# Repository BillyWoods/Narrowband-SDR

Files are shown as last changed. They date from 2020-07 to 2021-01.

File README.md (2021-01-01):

# Narrowband-SDR
A four-channel narrowband SDR receiver based around the Mirics MSi001, Maxim MAX19777 and Cypress FX2LP.

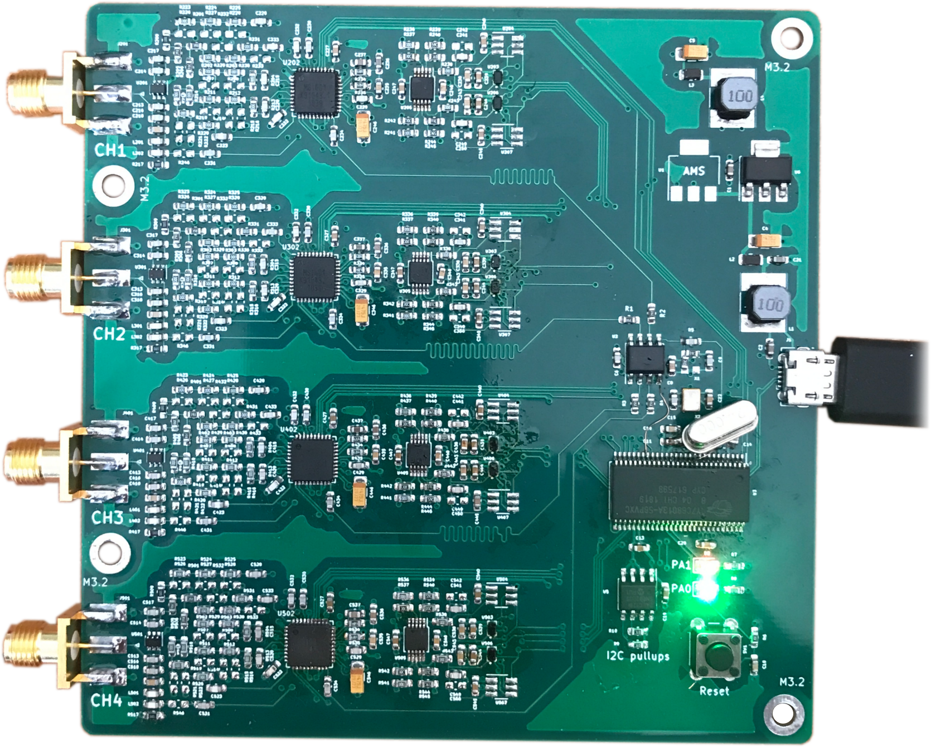
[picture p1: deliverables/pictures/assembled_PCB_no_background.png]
PCB picture
|  | system diagram |
|---|---|
| single channel spectrogram | four channel time domain |

## Project Layout
* Simulations of the RF architecture are in the **simulations/** folder.
* KiCAD PCB designs are in the **pcb/** folder.
* Firmware running on the Cypress FX2LP is stored in the **fx2fw/fx2sdr** folder. A copy of fx2lib is also included, which the firmware is built on, and fx2lib also provides utilities to upload/program the firmware to the device (fx2load).
* A branch of GNURadio (WiP) with support for this SDR is under development in the **host/** folder. However, at present data is pulled off the SDR and stored into raw files for later analysis using a tool in **fx2fw/uhd_driver**.

## Dependencies
fx2lib has a few dependencies, which are needed to compile the firmware:
* make
* gcc
* libusb-1.0
* SDCC
* python 2.7
* swig

Having libusb installed will also allow the host utility to be compiled.

## Acknowledgements
I would  like  to  thank Dr  Emanuele  Viterbo, of Monash University’s ECSE faculty, who supervised the project at its inception and assisted in developing its scope.

The open source Sigrok project must be acknowledged for serving as an example of how to use the FX2LP at the core of this SDR for high speed data acquisition.  Similarly, the Osmocom project, which provides a driver for the tuners used in this SDR, has assisted with interfacing and configuring the MSi001 tuners used in this project.

[Antti's LinuxTV Blog](http://blog.palosaari.fi/2013/10/naked-hardware-13-logitec-ldt-1s310uj.html) provided pictures of the PCB of an actual MSi001 implementation which were vital to developing the schematics for this project.

## Further Documentation
For more details on the project, see the [final report](deliverables/FYP_report_final.pdf).

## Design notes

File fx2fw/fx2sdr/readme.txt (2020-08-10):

gpif_waveforms.gpf is a file for/created in the Cypress GPIF designer.
gpif_waveforms.c is exported from the Cypress GPIF Designer.
gpif_dat.c is autogenerated from gpif_waveforms.c by the Makefile

Starting a new firmware is easy.

1) The fw should build without modification.

> make # builds firmware.ihx
> make bix # builds firmware.bix
> make iic # builds firmware.iic

2) modify device.c to initialize your device and
   handle data according to your needs.

3) add more sources, gpif data etc.

4) modify the device descriptor (dscr.a51)

For a fast way to deploy, you can use the fx2load
package provided in examples/fx2

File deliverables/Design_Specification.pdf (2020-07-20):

# ECE 4094 Project A

# (SDR for Sounding Rocket Telemetry)

# Design Specification

| First Name | Last name | ID | Email
Supervisor | Emanuele | Viterbo | | Emanuele.Viterbo@monash.edu
Student 1 | William | Woods | 28806506 | wwoo0003@student.monash.edu

### Table of Contents

Introduction | 1
System Specifications | 1
Parts List | 1
Design Choices | 2
Narrowband vs. Wideband | 2
Multi-channel functionality | 2
Moving to a Receive-Only SDR (Originally Intended to Have Receive and Transmit) | 3
Extending to Four Receive Channels (Originally Two) | 3
Inclusion of a Low-Noise Amplifier (LNA) as a Pre-Amplifier | 3
Radiofrequency (RF) Front-End | 4
Software System | 5
References | 5

### Tables and Figures

Table 1: Parts List | 1
Figure 1: Electronics System Diagram | 4
Figure 2: Software System Diagram | 5

## Introduction

This design specification details the software and hardware architecture for a four-channel narrowband software-defined radio (SDR) receiver. It is the culmination of my FYP research in semester one so far, and it explains the rationale for changes that have been made to the initial proposal and updates the initial specifications to reflect what is realisable with the hardware that has been selected.
This specification also serves to allow verification of the soundness of the architecture, allow detailed design of a PCB and allow the development of software needed to tie this SDR into the existing ecosystem of open source SDR software. For a detailed breakdown of future tasks which need to be completed, and the timeline for doing so, including a Gantt chart, see the Progress Report.
For context, this project is primarily intended to be for use with Monash High Powered Rocketry’s rockets, originally as both the rocket-mounted telemetry transmitter and as the ground station receiver. However, as this specification will explain, with the design moving to be a receiver only, it will find use only in the latter application. Other secondary applications for this project are also expected to be found, given its multi-channel capability.

## System Specifications

At this stage of design, with the components selected, the system will meet the following specifications:
- Four independently tuneable receive channels
- 50Ω impedance inputs
- 3M 12-bit samples/second, which can be divided amongst the four channels, each channel having two outputs for I and Q
- Configurable receiver bandwidths of 200kHz and 300kHz
- 150kHz to 1.8GHz tuneable range

### Parts List

Table 1: Parts List
Part | Description | Cost, approx., AUD | Qty | Total Cost | Supplier
NXP BGU7045 | Low-noise amplifier (LNA) with bypass. Operates up to 1000 MHz and is used because it has a lower noise figure than the MSi001’s internal LNAs over that range. | $1 | 4 | $4 | Element 14, Mouser, Digi-Key, LCSC
Mirics MSi001 | Integrated multiband tuner chip. It is controlled over SPI and has baseband analogue I/Q outputs (two differential pairs, i.e. four lines). | $3 | 4 | $12 | AliExpress

Maxim MAX11131 | 12-bit ADC. 3Msps multiplexed between all input channels. The multiplexing scheme can be configured to automatically follow a schedule of which channels to sample from. | $15 | 1 | $21 | Element 14, Mouser, Digi-Key
Cypress FX2LP | USB 2.0 bridge. Used for reading samples from the ADC and transferring them over USB. Also takes commands from the PC and controls the tuners. | $20 | 1 | $21 | Element 14, Mouser, Digi-Key, LCSC, AliExpress
22 MHz TXCO, 2 ppm | Precision frequency reference. This will supply the tuners, with the ADC and the USB bridge chip supplied by another source. | $5 | 1 | $5 | Element 14, Mouser, Digi-Key, LCSC
Printed Circuit Board (PCB) | 4-layer PCB, smaller than 100 x 100mm. Price includes registered shipping and minimum order quantity of five pieces. | $40 | 1 | $40 | JLCPCB
Total | | | | $103

### Design Choices

Narrowband vs. Wideband
There are existing SDR radios which work on bandwidths in the range of tens of megahertz, however these are expensive systems, particularly due to cost in the area of digitisation (the ADC) and digital electronics required as data rates increase.
Each of the radiofrequency (RF) tuners proposed for this design can provide reception of almost 10MHz of bandwidth and provide convenient analogue baseband I/Q outputs, so it is unfortunate to be underutilising these tuners in this project. However, to fully utilise the MSi001 tuners would push this SDR up into the price range and capability of pre-existing SDR systems; see the SDRplay RSP1A [1] for an existing single-channel receiver which fully utilises the MSi001.
To avoid re-inventing the wheel, it has been decided to differentiate this project by providing narrowband reception only, and thus saving on cost. There are still many things possible with a narrowband SDR (especially an SDR with four channels), and reception of most of the telemetry systems Monash High Powered Rocketry uses would be covered.
Multi-channel functionality
When the project was conceived, it was specified that the SDR should have multiple receivers synchronised to the same frequency reference. This choice was made because there are few affordable multi-channel SDRs available, yet such an SDR would be useful for experiments with diversity, direction finding and potentially beam forming.

Moving to a Receive-Only SDR (Originally Intended to Have Receive and Transmit)
The design moved to be a receive-only radio system, making this radio suitable for the telemetry ground station, but not useful onboard a rocket, which has to transmit the data. This decision was made due to anticipating difficulties with licensing.
A non-assigned scientific licence [2] can be obtained from the Australian Communications and Media Authority (ACMA) which permits research, teaching, demonstrations and trials on a set of shared frequencies. In fact, low power experimentation with SDRs in a shielded lab environment is already done at Monash University, however the end goal is to use this SDR “in the wild” on an ongoing basis and not as a demonstration or trial. The most appropriate licence for this is the low interference potential devices (LIPD) class licence [3], which does not require operators to apply for a licence, and covers mobile phones, cordless handsets, Wi-Fi, alarm systems, as examples. An apparatus licence [4], of which the amateur apparatus licence (colloquially known as the “HAM licence”) is a type, can also allow operation on a few more bands and power levels, but requires an operator to apply for it. However, in order for any radio transmitter device to be supplied and used in Australia under the LIPD class licence, the device needs to be certified for compliance [5]. Getting an SDR transmitter certified was found to be unlikely because it is such a general device, able to operate over a wide range of spectrum, with infinitely many different modulation schemes and different power levels, while the LIPD class licence is very explicit about what combinations of modulation schemes, bands and power levels may be used [6]. A few existing SDRs with transmit capability (at least ones made/distributed by US companies), attempt, in some cases, to circumvent similar legislation in their jurisdiction by classing SDRs as test equipment, however this is evidently a grey area if one does not hold a scientific or apparatus licence to operate such test equipment.
In any case, the complexity of dealing with licensing was felt to detract from the objectives of learning about radio design and producing a readily useable SDR.
Extending to Four Receive Channels (Originally Two)
While searching for discrete components for the RF front end (such as mixers, frequency synthesisers and filters), it was discovered that because only receive capability is required, a range of highly integrated tuners/front ends normally intended for cable and terrestrial TV applications would be suitable. Since these tuners are cheap and require few additional components, the cost to add additional receive channels is surprisingly small, so it was felt that the extra cost and design size were easily justified by the potential of having four phase-coherent, separately tuneable channels. Inclusion of a Low-Noise Amplifier (LNA) as a Pre-Amplifier
The MSi001 tuner has integrated LNAs, however it was decided to include a discrete LNA to assist in three ways. Firstly, the noise figures of the integrated LNAs are approximately 6dB, whereas the external LNA which has been chosen (BGU7045), has a noise figure which is half this, and the noise introduced by amplifiers early in the chain is particularly crucial to performance. Secondly, the external LNAs have an IIP3 of 15dBm at max gain, which is greater than the IIP3 of approximately -10dBm which the MSi001 has at its max gain, indicating that the MSi001 will be more susceptible to intermodulation from powerful interferers if it is being run at max gain, so by not needing to run the MSi001 at max gain, its IIP3 is much improved. Thirdly, the MSi001 has a gap in its reception between approximately 240 – 470MHz, but luckily there is a ‘hack,’ or workaround, to allow operation in this band. The workaround involves routing the RF signal through a signal path within the tuner normally intended for reception between 150kHz to 30MHz. The integrated LNA and mixer used in this path are not expected to have much response to a signal that is so far outside their operating ranges, so the inclusion of an external LNA is intended to assist here.

## Radiofrequency (RF) Front-End

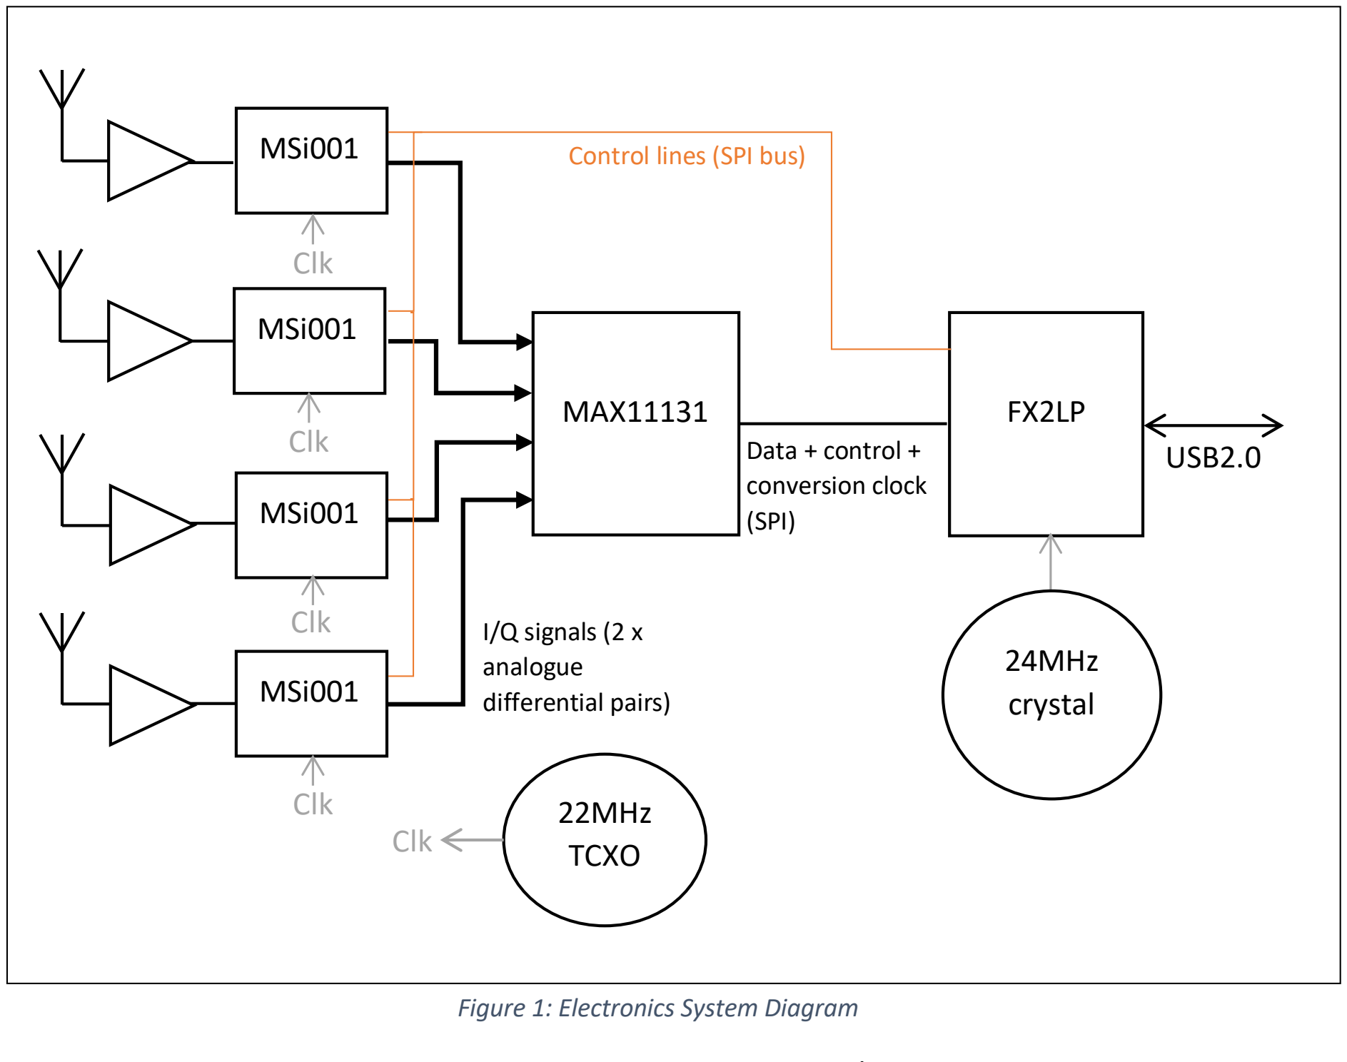
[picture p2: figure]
Figure 1: Electronics System Diagram; MSi001; MAX11131; 22MHz TCXO; Control lines (SPI bus); Clk; Data + control + conversion clock (SPI); USB2.0; I/Q signals (2 x analogue differential pairs); 24MHz crystal

All MSi001 tuners will run from the same precision oscillator/reference, while the FX2LP, per its datasheet, needs a 24MHz crystal. It is unfortunate that the MSi001 cannot operate from a 24MHz reference, otherwise an extra part could be eliminated. The FX2LP will be able to output a 48MHz clock on the SPI bus, which the ADC can use for both making conversions and communication.
Not pictured in Figure 1 is that the LNAs have internal bypass capability if no amplification is desired. This is controlled by setting the voltage of the gain control pin on the external LNAs to zero, so these control pins will be connected to the (digital) GPIO of the FX2LP, to at least provide a choice max gain or bypass.
Note that each MSi001 outputs an in-phase analogue output as a pseudo-differential pair and also a quadrature analogue output as another differential pair. This means that all 16 analogue inputs of the MAX11131 ADC are used to sample from 8 pseudo-differential channels. Each analogue line ranges from 0V to VCC (which will likely be chosen as 3.3V), centred around a common mode voltage of VCC/2 (this is the pseudo-differential scheme), and output clipping occurs at 3V peak-to-peak, differential. This is well-matched to the analogue inputs of the MAX11131 in unipolar/pseudo-differential mode, which can cover a range from 0V to VDD (which again will likely be chosen as 3.3V). However, not pictured in Figure 1 is that buffering may be required between the MSi001 and the MAX11131, because the analogue outputs of the MSi001 are fairly high impedance, being unable to drive a resistance smaller than 5kΩ and a capacitance greater than 20pF.

## Software System

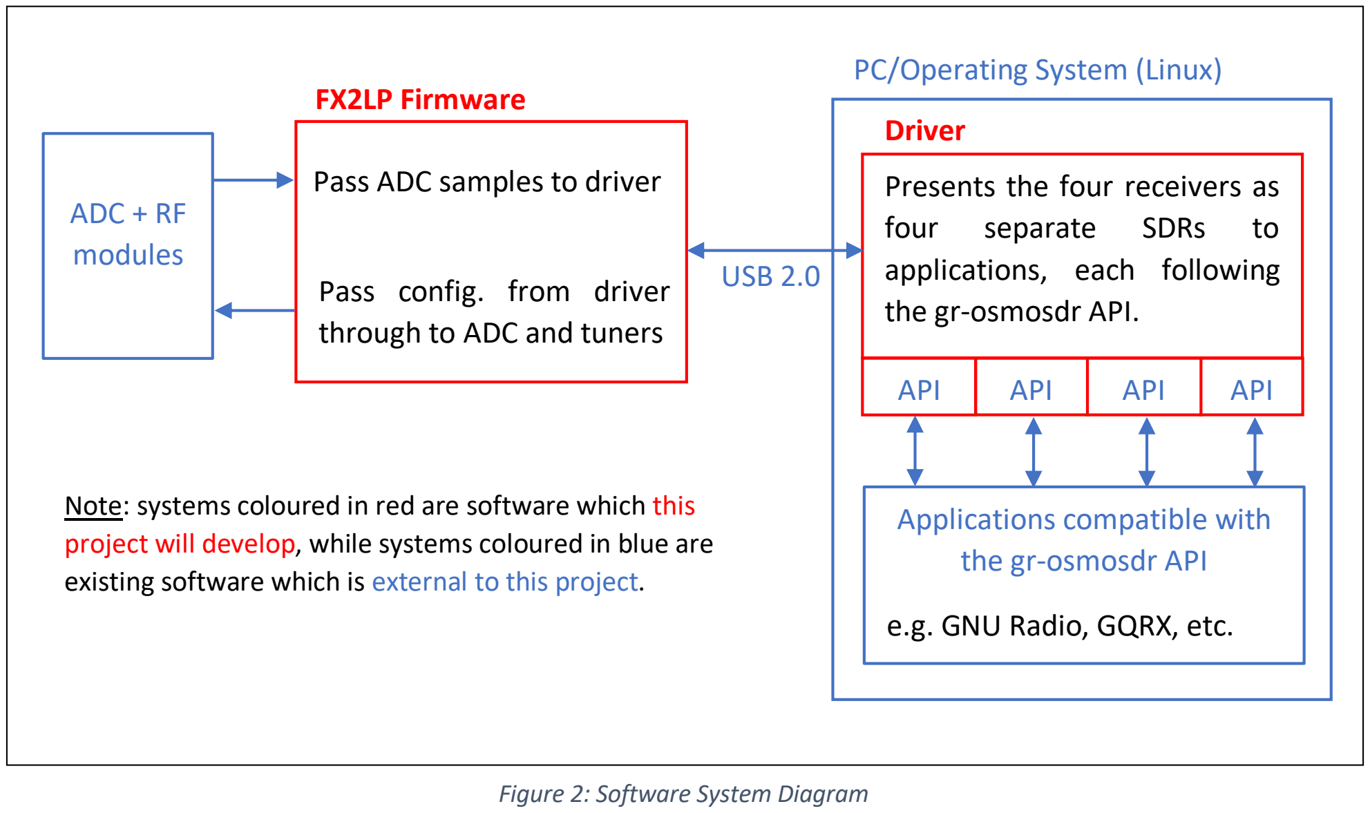
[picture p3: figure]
ADC + RF modules; FX2LP Firmware; Driver; PC/Operating System (Linux); Applications compatible with the gr-osmosdr API; e.g. GNU Radio, GQRX, etc.; API; Presents the four receivers as four separate SDRs to applications, each following the gr-osmosdr API.; USB 2.0; Pass ADC samples to driver; Pass config. from driver through to ADC and tuners; Figure 2: Software System Diagram

The driver will be developed initially for Linux, and will be derived from the existing open source libmirisdr drivers [7], [8]. These existing drivers present a single receiver (made up of an MSi001 tuner and an MSi2500 ADC + USB bridge) to applications following the gr-osmosdr API. The libmirisdr drivers will act as an excellent starting point but are expected to require extensive modification and testing, as the SDR of this design specification contains multiple MSi001 tuners and uses a very different ADC and USB bridge. Further, by having the driver expose a standard API which has been widely used in the open source SDR ecosystem (the API used by gr-osmosdr devices) it will be more straightforward to leverage that ecosystem.
The firmware that needs to be written for the Cypress FX2LP will control the tuners via a shared SPI bus, passing register configurationsreceived from the driver via USB. The second SPI bus on the FX2LP will need to run at 48MHz and will be dedicated entirely to retrieving samples from the ADC (and, in the reverse direction, for configuring the ADC). The driver will then be responsible for the bulk transfer of 12-bit samples over USB, back to the driver. The FX2LP also has a multitude of GPIO ports, some of which will be exposed to the driver and used for slow signalling, including enabling and disabling the external LNAs, turning on and off indicator LEDs, etc.

## References

[1] SDRplay, “RSP1A - SDRplay,” [Online]. Available: https://www.sdrplay.com/rsp1a/. [Accessed 9 June 2020].

Note: systems coloured in red are software which this project will develop, while systems coloured in blue are existing software which is external to this project.

[2] Australian Communications and Media Authority, “Scientific licence,” 18 May 2020. [Online]. Available: https://www.acma.gov.au/licences/scientific-licence. [Accessed 9 June 2020].
[3] Australian Communications and Media Authority, “Low interference potential devices (LIPD) class licence,” 30 January 2020. [Online]. Available: https://www.acma.gov.au/licences/low-interference-potential-devices-lipd-class-licence. [Accessed 9 June 2020].
[4] Australian Communications and Media Authority, “Apparatus licences,” 14 February 2020. [Online]. Available: https://www.acma.gov.au/apparatus-licences. [Accessed 9 June 2020].
[5] Compliance Engineering, “Short Range RF Devices and Australian Compliance Requirements,” [Online]. Available: https://www.compeng.com.au/document-library/short-range-rf-devices-and-australian-compliance-requirements/. [Accessed 9 June 2020].
[6] Australian Government, Radiocommunications (Low Interference Potential Devices) Class Licence, 2015.
[7] osmocom and various contributors, “libmirisdr - GitHub,” [Online]. Available: https://github.com/osmocom/libmirisdr.
[8] f4exb and various contributors, “libmirisdr-4 - GitHub,” [Online]. Available: https://github.com/f4exb/libmirisdr-4.

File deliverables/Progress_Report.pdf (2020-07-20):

# ECE 4094 Project A

# (SDR for Sounding Rocket Telemetry)

# Progress Report

| First Name | Last name | ID | Email
Supervisor | Emanuele | Viterbo | | Emanuele.Viterbo@monash.edu
Student 1 | William | Woods | 28806506 | wwoo0003@student.monash.edu

## Table of Contents

Objectives | 1
Progress to Date | 1
Selection of Major Components and Architecture: | 1
Relevant Background Study: | 1
Study on PCB Design Techniques: | 2
Research on Existing Software Which May be Suitable: | 2
Work to be Completed | 3
Proposed Gantt Chart of Work to be Completed | 5

## Tables and Figures

Table 1: Work to be Completed, Time Estimates and Dependencies | 3
Figure 1: Proposed Gantt Chart of Work to be Completed (Project Timeline) | 5

## Objectives

- To design and construct a Software Defined Radio platform (SDR) per the specifications outlined in the Design Specification
- Simulate the expected performance of the system, as part of the design phase
- Verify the operation of the constructed system against what was expected from simulation of the design
- By writing appropriate software, interface the SDR with the existing ecosystem of SDR software
- Learn a lot about RF engineering, produce a useful SDR and an interesting report/presentation!

## Progress to Date

The majority of Semester 1 2020 has been spent gaining familiarity with the required concepts needed to be able to design a radio receiver and then searching for appropriate parts (appropriate in terms of cost and capability).

### Selection of Major Components and Architecture:

A range of suitable RF hardware and ADCs has been reviewed, and an architecture has been developed around the following parts:
- BGU7045 (LNA)
- MSi001 (tuner)
- MAX11131 (ADC)
- FX2LP (microcontroller used as a USB 2.0 bridge; makes it easy to send samples from the ADC over USB)

### Relevant Background Study:

I have gained some familiarity with concepts related to RF I haven’t encountered before, including:
- Receiver architectures
- Multistage superheterodyne and choice of intermediate frequencies
- Single stage down to Low-IF or zero-IF
- Direct digital down conversion
- Mixing (for up conversion and down conversion)
- Image rejection
- Techniques for achieving it
- How it is tested/measured
- Non-linearities (in amplifiers)
- Intermodulation distortion (IMD)
- 1dB compression point
- Third order intercept point (OIP3, IIP3)
- Calculating noise figure, intermodulation products and gain through a chain of components
- Impedance matching
- Smith charts
- Controlled impedance traces
- Balanced and unbalanced signals
- Characterisation of phase noise

### Study on PCB Design Techniques:

I have researched PCB design for RF and analogue electronics, and compiled some guidelines:
- Use a four-layer PCB, with a stack-up like so:
1. Signals (RF, particularly)
2. Uninterrupted ground plane
3. Uninterrupted power plane
4. Other signals
- Keep RF signals on the same layer
- Route RF signals first, then digital signals, then power
- Keep high speed digital signals away from RF
- Baluns and filters can be found as small SMD components
- Try to use the most integrated components possible
- Use a trace impedance calculator (provided by most PCB manufacturing houses) to figure out the dimensions of the RF traces
- Provide decoupling on all digital chips (usually per the manufacturer’s recommendations).

### Research on Existing Software Which May be Suitable:

The libmirisdr and libmirisdr-4 drivers, which are open source and contain code to control the Mirics MSi001, have been looked into, and the registers they manipulate to control the MSi001 appear to correspond very well to the MSi001 datasheet. This means the control commands from these drivers should be easy to pass through the FX2LP to the tuners. However, the return path--the bulk data transfer from the ADC(s)--has not been looked into yet. It is unknown yet how much of the rest of the open source driver will be reusable, especially given this SDR will have four tuners and will use different ADC and USB hardware to the target of the libmirisdr drivers.

## Work to be Completed

Table 1: Work to be Completed, Time Estimates and Dependencies

Task | Time Estimate | Dependencies
1. Complete the selection of parts: Some components need to be investigated further to determine suitable parts, including: • Crystals/oscillators required for the RF/ADC/digital circuits • Passive supporting circuitry around all the other components. Most of this will be sourced from reference designs, however a reference design hasn’t been found for the MSi001 tuner yet. | 15 hours Specifying suitable oscillators/crystals and simple components such as voltage regulators, decoupling capacitors, resistors, etc. should not be too time-consuming. However, figuring out the specifications for the RF passives and sourcing them is expected to be more difficult, as this is not something I have done before. | None
2. Characterise the design:

I have yet to apply these RF concepts to analyse the design so that its characteristics can be theoretically calculated.

It would be good to know the final performance of the design on a few points:
- Sensitivity
- Noise floor
- Gain
- Susceptibility to IMD from nearby high-power signals (e.g. FM stations)
- Phase noise
- Frequency drift and offset
- I/Q phase error
Some of these can be derived from the datasheet of the tuner, however others will need a bit of analysis and simulation.

Once the component choice has been verified at this level, PCB layout can be started.

10 hours to work through a rough back-of-the-envelope calculation in a few operating regions/conditions.

20 hours of additional work to develop a Simulink model using the RF toolbox, which will allow more complex and thorough
analysis.

Partial dependency on Task 1 because a frequency
reference needs to be
selected in order to
approximate phase noise
and frequency drift.

3. Design the PCB A large part of this will involve searching for reference designs for the MSi001 tuner. This will help a lot. If such designs can’t be found, then studying reference designs for other tuners will be helpful. | 40 hours | Depends on Tasks 1 and 2
4. Order and assemble PCB and components | 2 to 4 weeks for manufacturing and shipping. 4 weeks lead time on the Mirics MSi001 tuners. I am allowing this time as these have to be sourced from less reputable suppliers. 2 weeks lead time on all other components. 2 weeks lead time on the PCB | Depends on Task 3 However, the MSi001 tuners should be ordered immediately upon smooth completion of Task 2, because they have the most uncertain lead time, yet are almost guaranteed to be utilised in the final design.
5. Write firmware to run on the FX2LP to handle: • Bulk transfer of ADC samples over USB • Passing of control signals/data (from the driver) received over USB to the tuners The firmware on the FX2LP will be simple because it acts only as a bridge, with most of the complexity shifted onto the driver running on the host computer. | 30 hours This firmware will not be complex, acting only as a bridge, however it will require programming an unfamiliar chip with an unfamiliar toolchain, hence the large allotted time. Some research into the USB specification is also expected. | Depends on Task 4 to be able to perform final integration and testing. However, large portions of this task have no dependencies, as I already have a development board for this chip available.
6. Adapt the libmirisdr-4 driver so that it presents this SDR correctly to the existing ecosystem of SDR software as four independently tuneable radios. | 50 hours This task is expected to be the most complex part of the software, so a lot of time has been allotted. | Runs in parallel to Task 5 Similar to Task 5, enough is already known, and adequate hardware is on hand, to begin on large portions of this task.
7. Verify the performance of the SDR via lab testing and compare results with the theoretical design specifications. | 10 hours of lab time with test equipment 6 hours to analyse the data and compare it | Depends on all previous tasks
8. Presentation and reporting • Compile the final report. • Produce a presentation poster. | 30 hours | None; this task is completed throughout the design process.

### Proposed Gantt Chart of Work to be Completed

The project schedule will rely in large part on the winter break period, after semester one exams, for a timely completion. It is expected that during the break this project will receive undivided attention, hence why Tasks 2 and 3 appear shorter than would be assumed with the average 8 hours a week that I have found to be achievable during semester, which is quite limiting. Tasks 5 and 6 are also expected to have work begin on them during the winter break period, as they have components which can be completed independently.

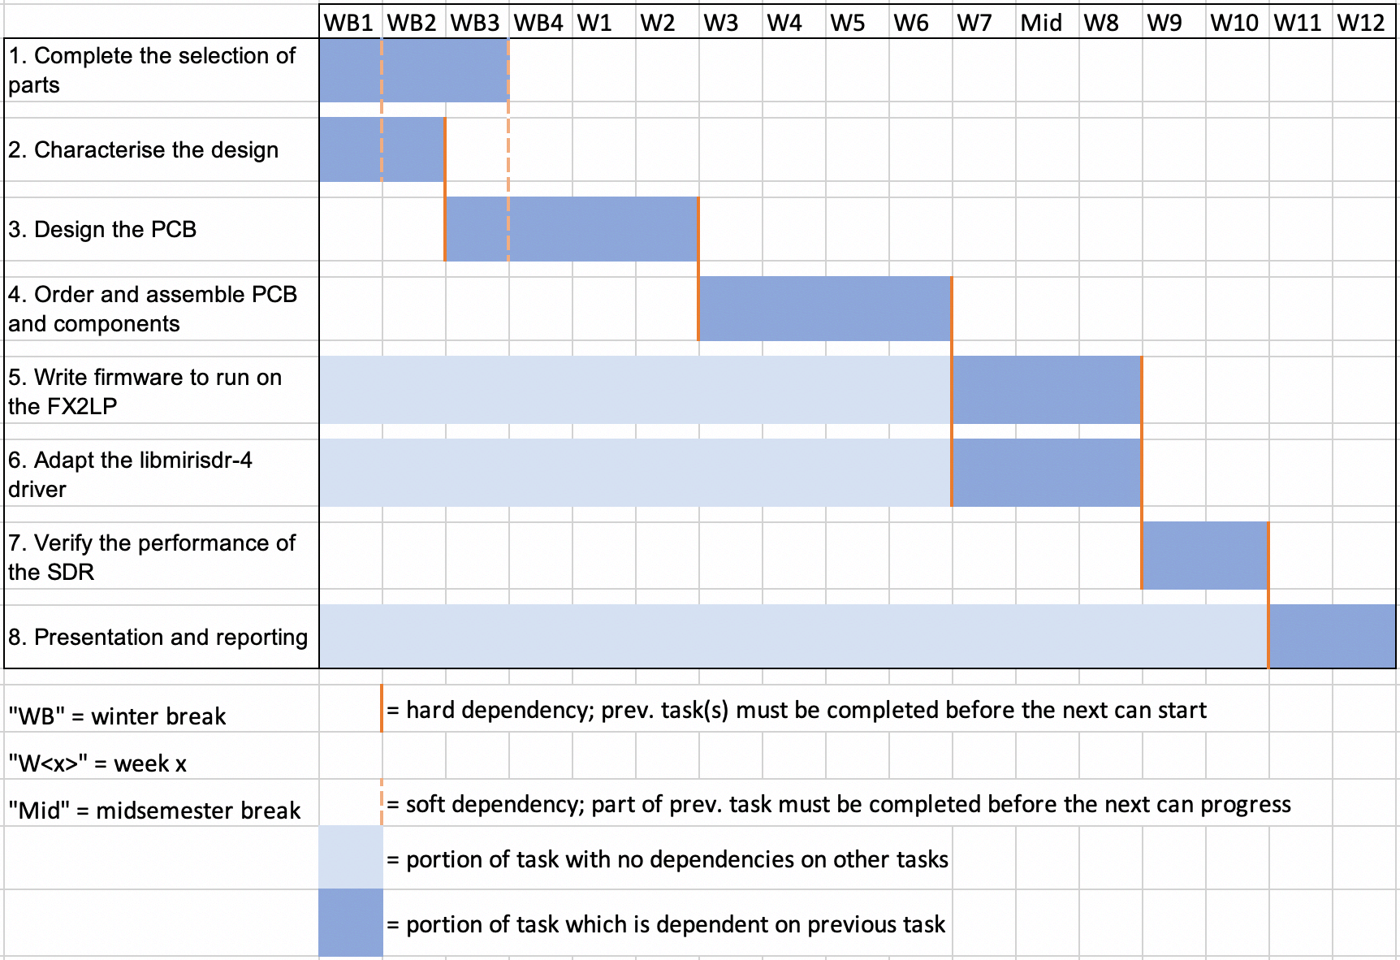
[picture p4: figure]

Figure 1: Proposed Gantt Chart of Work to be Completed (Project Timeline)

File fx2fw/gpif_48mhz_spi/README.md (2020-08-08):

What we need to do here:
	* Generate a 48MHz clock for the SPI bus (see the IFCLK)
	* Generate an nCS signal compliant with the MAX19777's usage of the CS line (see the CTL lines)
	* Capture 8 data input lines, read on every rising edge of the 48MHz clock (see the FD lines)
	* Setup the USB endpoint side of the FIFO buffers

Notes below pulled from datasheet "AN66806 - Getting Started With EZ-USB FX2LP GPIF". Emphasis added.

IFCLK (interface clock) is the reference clock for all GPIF operations. It can be an input or **output signal**;you can
select edge, rising, or falling as the active edge. As an input signal, it can be driven using an external clock in the
5 MHz to 48 MHz range. **As an output signal, IFCLK can be driven by FX2LP‘s internal clock at either 30 MHz or
48 MHz.**

CTL[5:0] (output only)
Control outputs provide signals required by the external peripheral such as **read/write strobes, enables,** and divided
clock. Only CTL[3:0] are available on the 56-pin package.

FD[15:0] (bidirectional)
The data bus is the conduit for payload data transferred between FX2LP endpoint FIFOs and the external peripheral.
It can be configured to operate as an **8-bit** or 16-bit interface and can be tristated if the system requires it. In 16-bit
mode, FD[7:0] represents the first byte in the endpoint FIFO and FD[15:8] represents the second byte.
FD[7:0] maps to PB[7:0] on the 56-pin package.

6 GSTATE[2:0] (output only)
Debug output signals represent the states executed in a GPIF waveform. These are connected to a logic analyzer for
debug purposes.

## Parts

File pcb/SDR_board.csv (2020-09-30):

Source: | /home/billy/Narrowband-SDR/pcb/SDR_board.sch
Date: | Wed 30 Sep 2020 14:20:49 AEST
Tool: | Eeschema 5.0.2-bee76a0~70~ubuntu18.04.1
Generator: | /usr/share/kicad/plugins/bom_csv_grouped_by_value.py
Component Count: | 463
Individual Components:
Item | Qty | Reference(s) | Value | LibPart | Footprint | Datasheet | Field4 | Field5 | Field6 | Field7 | Field8
 |  | C1 | 1uF | Device:C_Small | Capacitor_SMD:C_0603_1608Metric_Pad1.05x0.95mm_HandSolder | ~
 |  | C2 | 1uF | Device:C_Small | Capacitor_SMD:C_0603_1608Metric_Pad1.05x0.95mm_HandSolder | ~
 |  | C4 | 4.7uF | Device:CP_Small | Capacitor_SMD:C_1206_3216Metric_Pad1.42x1.75mm_HandSolder | ~
 |  | C5 | 4.7uF | Device:CP_Small | Capacitor_SMD:C_1206_3216Metric_Pad1.42x1.75mm_HandSolder | ~
 |  | C6 | 1nF | Device:C_Small | Capacitor_SMD:C_0603_1608Metric_Pad1.05x0.95mm_HandSolder | ~
 |  | C8 | 0.1uF | Device:C_Small | Capacitor_SMD:C_0603_1608Metric_Pad1.05x0.95mm_HandSolder | ~
 |  | C9 | 1nF | Device:C_Small | Capacitor_SMD:C_0603_1608Metric_Pad1.05x0.95mm_HandSolder | ~
 |  | C10 | 0.1uF | Device:C_Small | Capacitor_SMD:C_0603_1608Metric_Pad1.05x0.95mm_HandSolder | ~
 |  | C11 | 10nF | Device:C_Small | Capacitor_SMD:C_0603_1608Metric_Pad1.05x0.95mm_HandSolder | ~
 |  | C13 | 10nF | Device:C_Small | Capacitor_SMD:C_0603_1608Metric_Pad1.05x0.95mm_HandSolder | ~
 |  | C14 | 0.1uF | Device:C_Small | Capacitor_SMD:C_0603_1608Metric_Pad1.05x0.95mm_HandSolder | ~
 |  | C15 | 1nF | Device:C_Small | Capacitor_SMD:C_0603_1608Metric_Pad1.05x0.95mm_HandSolder | ~
 |  | C16 | 1nF | Device:C_Small | Capacitor_SMD:C_0603_1608Metric_Pad1.05x0.95mm_HandSolder | ~
 |  | C18 | 0.1uF | Device:C_Small | Capacitor_SMD:C_0603_1608Metric_Pad1.05x0.95mm_HandSolder | ~
 |  | C19 | 10nF | Device:C_Small | Capacitor_SMD:C_0603_1608Metric_Pad1.05x0.95mm_HandSolder | ~
 |  | C20 | 0.1uF | Device:C_Small | Capacitor_SMD:C_0603_1608Metric_Pad1.05x0.95mm_HandSolder | ~
 |  | C21 | 1uF | Device:C_Small | Capacitor_SMD:C_0603_1608Metric_Pad1.05x0.95mm_HandSolder | ~
 |  | C22 | 0.1uF | Device:C_Small | Capacitor_SMD:C_0603_1608Metric_Pad1.05x0.95mm_HandSolder | ~
 |  | C201 | 0.1uF | Device:C_Small | Capacitor_SMD:C_0603_1608Metric_Pad1.05x0.95mm_HandSolder | ~
 |  | C202 | 0.1uF | Device:C_Small | Capacitor_SMD:C_0603_1608Metric_Pad1.05x0.95mm_HandSolder | ~
 |  | C203 | 100pF | Device:C_Small | Capacitor_SMD:C_0603_1608Metric_Pad1.05x0.95mm_HandSolder | ~
 |  | C204 | 100pF | Device:C_Small | Capacitor_SMD:C_0603_1608Metric_Pad1.05x0.95mm_HandSolder | ~
 |  | C205 | 100pF | Device:C_Small | Capacitor_SMD:C_0603_1608Metric_Pad1.05x0.95mm_HandSolder | ~
 |  | C206 | 100pF | Device:C_Small | Capacitor_SMD:C_0603_1608Metric_Pad1.05x0.95mm_HandSolder | ~
 |  | C207 | 100pF | Device:C_Small | Capacitor_SMD:C_0603_1608Metric_Pad1.05x0.95mm_HandSolder | ~
 |  | C208 | 100pF | Device:C_Small | Capacitor_SMD:C_0603_1608Metric_Pad1.05x0.95mm_HandSolder | ~
 |  | C209 | 100pF | Device:C_Small | Capacitor_SMD:C_0603_1608Metric_Pad1.05x0.95mm_HandSolder | ~
 |  | C210 | 10nF | Device:C_Small | Capacitor_SMD:C_0603_1608Metric_Pad1.05x0.95mm_HandSolder | ~
 |  | C211 | 100pF | Device:C_Small | Capacitor_SMD:C_0603_1608Metric_Pad1.05x0.95mm_HandSolder | ~
 |  | C212 | 10nF | Device:C_Small | Capacitor_SMD:C_0603_1608Metric_Pad1.05x0.95mm_HandSolder | ~
 |  | C213 | 100pF | Device:C_Small | Capacitor_SMD:C_0603_1608Metric_Pad1.05x0.95mm_HandSolder | ~
 |  | C214 | 100pF | Device:C_Small | Capacitor_SMD:C_0603_1608Metric_Pad1.05x0.95mm_HandSolder | ~
 |  | C215 | 220pF | Device:C_Small | Capacitor_SMD:C_0603_1608Metric_Pad1.05x0.95mm_HandSolder | ~
 |  | C216 | 100pF | Device:C_Small | Capacitor_SMD:C_0603_1608Metric_Pad1.05x0.95mm_HandSolder | ~
 |  | C217 | 100pF | Device:C_Small | Capacitor_SMD:C_0603_1608Metric_Pad1.05x0.95mm_HandSolder | ~
 |  | C218 | 0.1uF | Device:C_Small | Capacitor_SMD:C_0603_1608Metric_Pad1.05x0.95mm_HandSolder | ~
 |  | C219 | 220pF | Device:C_Small | Capacitor_SMD:C_0603_1608Metric_Pad1.05x0.95mm_HandSolder | ~
 |  | C220 | 220pF | Device:C_Small | Capacitor_SMD:C_0603_1608Metric_Pad1.05x0.95mm_HandSolder | ~
 |  | C221 | 220pF | Device:C_Small | Capacitor_SMD:C_0603_1608Metric_Pad1.05x0.95mm_HandSolder | ~
 |  | C222 | 220pF | Device:C_Small | Capacitor_SMD:C_0603_1608Metric_Pad1.05x0.95mm_HandSolder | ~
 |  | C223 | 220pF | Device:C_Small | Capacitor_SMD:C_0603_1608Metric_Pad1.05x0.95mm_HandSolder | ~
 |  | C225 | 0.1uF | Device:C_Small | Capacitor_SMD:C_0603_1608Metric_Pad1.05x0.95mm_HandSolder | ~
 |  | C226 | 1uF | Device:C_Small | Capacitor_SMD:C_0603_1608Metric_Pad1.05x0.95mm_HandSolder | ~
 |  | C227 | 10nF | Device:C_Small | Capacitor_SMD:C_0603_1608Metric_Pad1.05x0.95mm_HandSolder | ~
 |  | C228 | 100pF | Device:C_Small | Capacitor_SMD:C_0603_1608Metric_Pad1.05x0.95mm_HandSolder | ~
 |  | C229 | 100pF | Device:C_Small | Capacitor_SMD:C_0603_1608Metric_Pad1.05x0.95mm_HandSolder | ~
 |  | C230 | 1nF | Device:C_Small | Capacitor_SMD:C_0603_1608Metric_Pad1.05x0.95mm_HandSolder | ~
 |  | C231 | 1nF | Device:C_Small | Capacitor_SMD:C_0603_1608Metric_Pad1.05x0.95mm_HandSolder | ~
 |  | C232 | 220pF | Device:C_Small | Capacitor_SMD:C_0603_1608Metric_Pad1.05x0.95mm_HandSolder | ~
 |  | C233 | 220pF | Device:C_Small | Capacitor_SMD:C_0603_1608Metric_Pad1.05x0.95mm_HandSolder | ~
 |  | C234 | 1nF | Device:C_Small | Capacitor_SMD:C_0603_1608Metric_Pad1.05x0.95mm_HandSolder | ~
 |  | C235 | 39nF | Device:C_Small | Capacitor_SMD:C_0603_1608Metric_Pad1.05x0.95mm_HandSolder | ~
 |  | C236 | 2.7nF | Device:C_Small | Capacitor_SMD:C_0603_1608Metric_Pad1.05x0.95mm_HandSolder | ~
 |  | C237 | 2.7nF | Device:C_Small | Capacitor_SMD:C_0603_1608Metric_Pad1.05x0.95mm_HandSolder | ~
 |  | C238 | 10nF | Device:C_Small | Capacitor_SMD:C_0603_1608Metric_Pad1.05x0.95mm_HandSolder | ~
 |  | C239 | 0.1uF | Device:C_Small | Capacitor_SMD:C_0603_1608Metric_Pad1.05x0.95mm_HandSolder | ~
 |  | C240 | 10nF | Device:C_Small | Capacitor_SMD:C_0603_1608Metric_Pad1.05x0.95mm_HandSolder | ~
 |  | C241 | 100pF | Device:C_Small | Capacitor_SMD:C_0603_1608Metric_Pad1.05x0.95mm_HandSolder | ~
 |  | C242 | 100pF | Device:C_Small | Capacitor_SMD:C_0603_1608Metric_Pad1.05x0.95mm_HandSolder | ~
 |  | C243 | 10nF | Device:C_Small | Capacitor_SMD:C_0603_1608Metric_Pad1.05x0.95mm_HandSolder | ~
 |  | C244 | 0.1uF | Device:C_Small | Capacitor_SMD:C_0603_1608Metric_Pad1.05x0.95mm_HandSolder | ~
 |  | C245 | 10nF | Device:C_Small | Capacitor_SMD:C_0603_1608Metric_Pad1.05x0.95mm_HandSolder | ~
 |  | C246 | 4.7uF | Device:CP_Small | Capacitor_SMD:C_1206_3216Metric_Pad1.42x1.75mm_HandSolder | ~
 |  | C247 | 10nF | Device:C_Small | Capacitor_SMD:C_0603_1608Metric_Pad1.05x0.95mm_HandSolder | ~
 |  | C248 | 0.1uF | Device:C_Small | Capacitor_SMD:C_0603_1608Metric_Pad1.05x0.95mm_HandSolder | ~
 |  | C249 | 100pF | Device:C_Small | Capacitor_SMD:C_0603_1608Metric_Pad1.05x0.95mm_HandSolder | ~
 |  | C250 | 100pF | Device:C_Small | Capacitor_SMD:C_0603_1608Metric_Pad1.05x0.95mm_HandSolder | ~
 |  | C301 | 0.1uF | Device:C_Small | Capacitor_SMD:C_0603_1608Metric_Pad1.05x0.95mm_HandSolder | ~
 |  | C302 | 0.1uF | Device:C_Small | Capacitor_SMD:C_0603_1608Metric_Pad1.05x0.95mm_HandSolder | ~
 |  | C303 | 100pF | Device:C_Small | Capacitor_SMD:C_0603_1608Metric_Pad1.05x0.95mm_HandSolder | ~
 |  | C304 | 100pF | Device:C_Small | Capacitor_SMD:C_0603_1608Metric_Pad1.05x0.95mm_HandSolder | ~
 |  | C305 | 100pF | Device:C_Small | Capacitor_SMD:C_0603_1608Metric_Pad1.05x0.95mm_HandSolder | ~
 |  | C306 | 100pF | Device:C_Small | Capacitor_SMD:C_0603_1608Metric_Pad1.05x0.95mm_HandSolder | ~
 |  | C307 | 100pF | Device:C_Small | Capacitor_SMD:C_0603_1608Metric_Pad1.05x0.95mm_HandSolder | ~
 |  | C308 | 100pF | Device:C_Small | Capacitor_SMD:C_0603_1608Metric_Pad1.05x0.95mm_HandSolder | ~
 |  | C309 | 100pF | Device:C_Small | Capacitor_SMD:C_0603_1608Metric_Pad1.05x0.95mm_HandSolder | ~
 |  | C310 | 10nF | Device:C_Small | Capacitor_SMD:C_0603_1608Metric_Pad1.05x0.95mm_HandSolder | ~
 |  | C311 | 100pF | Device:C_Small | Capacitor_SMD:C_0603_1608Metric_Pad1.05x0.95mm_HandSolder | ~
 |  | C312 | 10nF | Device:C_Small | Capacitor_SMD:C_0603_1608Metric_Pad1.05x0.95mm_HandSolder | ~
 |  | C313 | 100pF | Device:C_Small | Capacitor_SMD:C_0603_1608Metric_Pad1.05x0.95mm_HandSolder | ~
 |  | C314 | 100pF | Device:C_Small | Capacitor_SMD:C_0603_1608Metric_Pad1.05x0.95mm_HandSolder | ~
 |  | C315 | 220pF | Device:C_Small | Capacitor_SMD:C_0603_1608Metric_Pad1.05x0.95mm_HandSolder | ~
 |  | C316 | 100pF | Device:C_Small | Capacitor_SMD:C_0603_1608Metric_Pad1.05x0.95mm_HandSolder | ~
 |  | C317 | 100pF | Device:C_Small | Capacitor_SMD:C_0603_1608Metric_Pad1.05x0.95mm_HandSolder | ~
 |  | C318 | 0.1uF | Device:C_Small | Capacitor_SMD:C_0603_1608Metric_Pad1.05x0.95mm_HandSolder | ~
 |  | C319 | 220pF | Device:C_Small | Capacitor_SMD:C_0603_1608Metric_Pad1.05x0.95mm_HandSolder | ~
 |  | C320 | 220pF | Device:C_Small | Capacitor_SMD:C_0603_1608Metric_Pad1.05x0.95mm_HandSolder | ~
 |  | C321 | 220pF | Device:C_Small | Capacitor_SMD:C_0603_1608Metric_Pad1.05x0.95mm_HandSolder | ~
 |  | C322 | 220pF | Device:C_Small | Capacitor_SMD:C_0603_1608Metric_Pad1.05x0.95mm_HandSolder | ~
 |  | C323 | 220pF | Device:C_Small | Capacitor_SMD:C_0603_1608Metric_Pad1.05x0.95mm_HandSolder | ~
 |  | C325 | 0.1uF | Device:C_Small | Capacitor_SMD:C_0603_1608Metric_Pad1.05x0.95mm_HandSolder | ~
 |  | C326 | 1uF | Device:C_Small | Capacitor_SMD:C_0603_1608Metric_Pad1.05x0.95mm_HandSolder | ~
 |  | C327 | 10nF | Device:C_Small | Capacitor_SMD:C_0603_1608Metric_Pad1.05x0.95mm_HandSolder | ~
 |  | C328 | 100pF | Device:C_Small | Capacitor_SMD:C_0603_1608Metric_Pad1.05x0.95mm_HandSolder | ~
 |  | C329 | 100pF | Device:C_Small | Capacitor_SMD:C_0603_1608Metric_Pad1.05x0.95mm_HandSolder | ~
 |  | C330 | 1nF | Device:C_Small | Capacitor_SMD:C_0603_1608Metric_Pad1.05x0.95mm_HandSolder | ~
 |  | C331 | 1nF | Device:C_Small | Capacitor_SMD:C_0603_1608Metric_Pad1.05x0.95mm_HandSolder | ~
 |  | C332 | 220pF | Device:C_Small | Capacitor_SMD:C_0603_1608Metric_Pad1.05x0.95mm_HandSolder | ~
 |  | C333 | 220pF | Device:C_Small | Capacitor_SMD:C_0603_1608Metric_Pad1.05x0.95mm_HandSolder | ~
 |  | C334 | 1nF | Device:C_Small | Capacitor_SMD:C_0603_1608Metric_Pad1.05x0.95mm_HandSolder | ~
 |  | C335 | 39nF | Device:C_Small | Capacitor_SMD:C_0603_1608Metric_Pad1.05x0.95mm_HandSolder | ~
 |  | C336 | 2.7nF | Device:C_Small | Capacitor_SMD:C_0603_1608Metric_Pad1.05x0.95mm_HandSolder | ~
 |  | C337 | 2.7nF | Device:C_Small | Capacitor_SMD:C_0603_1608Metric_Pad1.05x0.95mm_HandSolder | ~
 |  | C338 | 10nF | Device:C_Small | Capacitor_SMD:C_0603_1608Metric_Pad1.05x0.95mm_HandSolder | ~
 |  | C339 | 0.1uF | Device:C_Small | Capacitor_SMD:C_0603_1608Metric_Pad1.05x0.95mm_HandSolder | ~
 |  | C340 | 10nF | Device:C_Small | Capacitor_SMD:C_0603_1608Metric_Pad1.05x0.95mm_HandSolder | ~
 |  | C341 | 100pF | Device:C_Small | Capacitor_SMD:C_0603_1608Metric_Pad1.05x0.95mm_HandSolder | ~
 |  | C342 | 100pF | Device:C_Small | Capacitor_SMD:C_0603_1608Metric_Pad1.05x0.95mm_HandSolder | ~
 |  | C343 | 10nF | Device:C_Small | Capacitor_SMD:C_0603_1608Metric_Pad1.05x0.95mm_HandSolder | ~
 |  | C344 | 0.1uF | Device:C_Small | Capacitor_SMD:C_0603_1608Metric_Pad1.05x0.95mm_HandSolder | ~
 |  | C345 | 10nF | Device:C_Small | Capacitor_SMD:C_0603_1608Metric_Pad1.05x0.95mm_HandSolder | ~
 |  | C346 | 4.7uF | Device:CP_Small | Capacitor_SMD:C_1206_3216Metric_Pad1.42x1.75mm_HandSolder | ~
 |  | C347 | 10nF | Device:C_Small | Capacitor_SMD:C_0603_1608Metric_Pad1.05x0.95mm_HandSolder | ~
 |  | C348 | 0.1uF | Device:C_Small | Capacitor_SMD:C_0603_1608Metric_Pad1.05x0.95mm_HandSolder | ~
 |  | C349 | 100pF | Device:C_Small | Capacitor_SMD:C_0603_1608Metric_Pad1.05x0.95mm_HandSolder | ~
 |  | C350 | 100pF | Device:C_Small | Capacitor_SMD:C_0603_1608Metric_Pad1.05x0.95mm_HandSolder | ~
 |  | C401 | 0.1uF | Device:C_Small | Capacitor_SMD:C_0603_1608Metric_Pad1.05x0.95mm_HandSolder | ~
 |  | C402 | 0.1uF | Device:C_Small | Capacitor_SMD:C_0603_1608Metric_Pad1.05x0.95mm_HandSolder | ~
 |  | C403 | 100pF | Device:C_Small | Capacitor_SMD:C_0603_1608Metric_Pad1.05x0.95mm_HandSolder | ~
 |  | C404 | 100pF | Device:C_Small | Capacitor_SMD:C_0603_1608Metric_Pad1.05x0.95mm_HandSolder | ~
 |  | C405 | 100pF | Device:C_Small | Capacitor_SMD:C_0603_1608Metric_Pad1.05x0.95mm_HandSolder | ~
 |  | C406 | 100pF | Device:C_Small | Capacitor_SMD:C_0603_1608Metric_Pad1.05x0.95mm_HandSolder | ~
 |  | C407 | 100pF | Device:C_Small | Capacitor_SMD:C_0603_1608Metric_Pad1.05x0.95mm_HandSolder | ~
 |  | C408 | 100pF | Device:C_Small | Capacitor_SMD:C_0603_1608Metric_Pad1.05x0.95mm_HandSolder | ~
 |  | C409 | 100pF | Device:C_Small | Capacitor_SMD:C_0603_1608Metric_Pad1.05x0.95mm_HandSolder | ~
 |  | C410 | 10nF | Device:C_Small | Capacitor_SMD:C_0603_1608Metric_Pad1.05x0.95mm_HandSolder | ~
 |  | C411 | 100pF | Device:C_Small | Capacitor_SMD:C_0603_1608Metric_Pad1.05x0.95mm_HandSolder | ~
 |  | C412 | 10nF | Device:C_Small | Capacitor_SMD:C_0603_1608Metric_Pad1.05x0.95mm_HandSolder | ~
 |  | C413 | 100pF | Device:C_Small | Capacitor_SMD:C_0603_1608Metric_Pad1.05x0.95mm_HandSolder | ~
 |  | C414 | 100pF | Device:C_Small | Capacitor_SMD:C_0603_1608Metric_Pad1.05x0.95mm_HandSolder | ~
 |  | C415 | 220pF | Device:C_Small | Capacitor_SMD:C_0603_1608Metric_Pad1.05x0.95mm_HandSolder | ~
 |  | C416 | 100pF | Device:C_Small | Capacitor_SMD:C_0603_1608Metric_Pad1.05x0.95mm_HandSolder | ~
 |  | C417 | 100pF | Device:C_Small | Capacitor_SMD:C_0603_1608Metric_Pad1.05x0.95mm_HandSolder | ~
 |  | C418 | 0.1uF | Device:C_Small | Capacitor_SMD:C_0603_1608Metric_Pad1.05x0.95mm_HandSolder | ~
 |  | C419 | 220pF | Device:C_Small | Capacitor_SMD:C_0603_1608Metric_Pad1.05x0.95mm_HandSolder | ~
 |  | C420 | 220pF | Device:C_Small | Capacitor_SMD:C_0603_1608Metric_Pad1.05x0.95mm_HandSolder | ~
 |  | C421 | 220pF | Device:C_Small | Capacitor_SMD:C_0603_1608Metric_Pad1.05x0.95mm_HandSolder | ~
 |  | C422 | 220pF | Device:C_Small | Capacitor_SMD:C_0603_1608Metric_Pad1.05x0.95mm_HandSolder | ~
 |  | C423 | 220pF | Device:C_Small | Capacitor_SMD:C_0603_1608Metric_Pad1.05x0.95mm_HandSolder | ~
 |  | C425 | 0.1uF | Device:C_Small | Capacitor_SMD:C_0603_1608Metric_Pad1.05x0.95mm_HandSolder | ~
 |  | C426 | 1uF | Device:C_Small | Capacitor_SMD:C_0603_1608Metric_Pad1.05x0.95mm_HandSolder | ~
 |  | C427 | 10nF | Device:C_Small | Capacitor_SMD:C_0603_1608Metric_Pad1.05x0.95mm_HandSolder | ~
 |  | C428 | 100pF | Device:C_Small | Capacitor_SMD:C_0603_1608Metric_Pad1.05x0.95mm_HandSolder | ~
 |  | C429 | 100pF | Device:C_Small | Capacitor_SMD:C_0603_1608Metric_Pad1.05x0.95mm_HandSolder | ~
 |  | C430 | 1nF | Device:C_Small | Capacitor_SMD:C_0603_1608Metric_Pad1.05x0.95mm_HandSolder | ~
 |  | C431 | 1nF | Device:C_Small | Capacitor_SMD:C_0603_1608Metric_Pad1.05x0.95mm_HandSolder | ~
 |  | C432 | 220pF | Device:C_Small | Capacitor_SMD:C_0603_1608Metric_Pad1.05x0.95mm_HandSolder | ~
 |  | C433 | 220pF | Device:C_Small | Capacitor_SMD:C_0603_1608Metric_Pad1.05x0.95mm_HandSolder | ~
 |  | C434 | 1nF | Device:C_Small | Capacitor_SMD:C_0603_1608Metric_Pad1.05x0.95mm_HandSolder | ~
 |  | C435 | 39nF | Device:C_Small | Capacitor_SMD:C_0603_1608Metric_Pad1.05x0.95mm_HandSolder | ~
 |  | C436 | 2.7nF | Device:C_Small | Capacitor_SMD:C_0603_1608Metric_Pad1.05x0.95mm_HandSolder | ~
 |  | C437 | 2.7nF | Device:C_Small | Capacitor_SMD:C_0603_1608Metric_Pad1.05x0.95mm_HandSolder | ~
 |  | C438 | 10nF | Device:C_Small | Capacitor_SMD:C_0603_1608Metric_Pad1.05x0.95mm_HandSolder | ~
 |  | C439 | 0.1uF | Device:C_Small | Capacitor_SMD:C_0603_1608Metric_Pad1.05x0.95mm_HandSolder | ~
 |  | C440 | 10nF | Device:C_Small | Capacitor_SMD:C_0603_1608Metric_Pad1.05x0.95mm_HandSolder | ~
 |  | C441 | 100pF | Device:C_Small | Capacitor_SMD:C_0603_1608Metric_Pad1.05x0.95mm_HandSolder | ~
 |  | C442 | 100pF | Device:C_Small | Capacitor_SMD:C_0603_1608Metric_Pad1.05x0.95mm_HandSolder | ~
 |  | C443 | 10nF | Device:C_Small | Capacitor_SMD:C_0603_1608Metric_Pad1.05x0.95mm_HandSolder | ~
 |  | C444 | 0.1uF | Device:C_Small | Capacitor_SMD:C_0603_1608Metric_Pad1.05x0.95mm_HandSolder | ~
 |  | C445 | 10nF | Device:C_Small | Capacitor_SMD:C_0603_1608Metric_Pad1.05x0.95mm_HandSolder | ~
 |  | C446 | 4.7uF | Device:CP_Small | Capacitor_SMD:C_1206_3216Metric_Pad1.42x1.75mm_HandSolder | ~
 |  | C447 | 10nF | Device:C_Small | Capacitor_SMD:C_0603_1608Metric_Pad1.05x0.95mm_HandSolder | ~
 |  | C448 | 0.1uF | Device:C_Small | Capacitor_SMD:C_0603_1608Metric_Pad1.05x0.95mm_HandSolder | ~
 |  | C449 | 100pF | Device:C_Small | Capacitor_SMD:C_0603_1608Metric_Pad1.05x0.95mm_HandSolder | ~
 |  | C450 | 100pF | Device:C_Small | Capacitor_SMD:C_0603_1608Metric_Pad1.05x0.95mm_HandSolder | ~
 |  | C501 | 0.1uF | Device:C_Small | Capacitor_SMD:C_0603_1608Metric_Pad1.05x0.95mm_HandSolder | ~
 |  | C502 | 0.1uF | Device:C_Small | Capacitor_SMD:C_0603_1608Metric_Pad1.05x0.95mm_HandSolder | ~
 |  | C503 | 100pF | Device:C_Small | Capacitor_SMD:C_0603_1608Metric_Pad1.05x0.95mm_HandSolder | ~
 |  | C504 | 100pF | Device:C_Small | Capacitor_SMD:C_0603_1608Metric_Pad1.05x0.95mm_HandSolder | ~
 |  | C505 | 100pF | Device:C_Small | Capacitor_SMD:C_0603_1608Metric_Pad1.05x0.95mm_HandSolder | ~
 |  | C506 | 100pF | Device:C_Small | Capacitor_SMD:C_0603_1608Metric_Pad1.05x0.95mm_HandSolder | ~
 |  | C507 | 100pF | Device:C_Small | Capacitor_SMD:C_0603_1608Metric_Pad1.05x0.95mm_HandSolder | ~
 |  | C508 | 100pF | Device:C_Small | Capacitor_SMD:C_0603_1608Metric_Pad1.05x0.95mm_HandSolder | ~
 |  | C509 | 100pF | Device:C_Small | Capacitor_SMD:C_0603_1608Metric_Pad1.05x0.95mm_HandSolder | ~
 |  | C510 | 10nF | Device:C_Small | Capacitor_SMD:C_0603_1608Metric_Pad1.05x0.95mm_HandSolder | ~
 |  | C511 | 100pF | Device:C_Small | Capacitor_SMD:C_0603_1608Metric_Pad1.05x0.95mm_HandSolder | ~
 |  | C512 | 10nF | Device:C_Small | Capacitor_SMD:C_0603_1608Metric_Pad1.05x0.95mm_HandSolder | ~
 |  | C513 | 100pF | Device:C_Small | Capacitor_SMD:C_0603_1608Metric_Pad1.05x0.95mm_HandSolder | ~
 |  | C514 | 100pF | Device:C_Small | Capacitor_SMD:C_0603_1608Metric_Pad1.05x0.95mm_HandSolder | ~
 |  | C515 | 220pF | Device:C_Small | Capacitor_SMD:C_0603_1608Metric_Pad1.05x0.95mm_HandSolder | ~
 |  | C516 | 100pF | Device:C_Small | Capacitor_SMD:C_0603_1608Metric_Pad1.05x0.95mm_HandSolder | ~
 |  | C517 | 100pF | Device:C_Small | Capacitor_SMD:C_0603_1608Metric_Pad1.05x0.95mm_HandSolder | ~
 |  | C518 | 0.1uF | Device:C_Small | Capacitor_SMD:C_0603_1608Metric_Pad1.05x0.95mm_HandSolder | ~
 |  | C519 | 220pF | Device:C_Small | Capacitor_SMD:C_0603_1608Metric_Pad1.05x0.95mm_HandSolder | ~
 |  | C520 | 220pF | Device:C_Small | Capacitor_SMD:C_0603_1608Metric_Pad1.05x0.95mm_HandSolder | ~
 |  | C521 | 220pF | Device:C_Small | Capacitor_SMD:C_0603_1608Metric_Pad1.05x0.95mm_HandSolder | ~
 |  | C522 | 220pF | Device:C_Small | Capacitor_SMD:C_0603_1608Metric_Pad1.05x0.95mm_HandSolder | ~
 |  | C523 | 220pF | Device:C_Small | Capacitor_SMD:C_0603_1608Metric_Pad1.05x0.95mm_HandSolder | ~
 |  | C525 | 0.1uF | Device:C_Small | Capacitor_SMD:C_0603_1608Metric_Pad1.05x0.95mm_HandSolder | ~
 |  | C526 | 1uF | Device:C_Small | Capacitor_SMD:C_0603_1608Metric_Pad1.05x0.95mm_HandSolder | ~
 |  | C527 | 10nF | Device:C_Small | Capacitor_SMD:C_0603_1608Metric_Pad1.05x0.95mm_HandSolder | ~
 |  | C528 | 100pF | Device:C_Small | Capacitor_SMD:C_0603_1608Metric_Pad1.05x0.95mm_HandSolder | ~
 |  | C529 | 100pF | Device:C_Small | Capacitor_SMD:C_0603_1608Metric_Pad1.05x0.95mm_HandSolder | ~
 |  | C530 | 1nF | Device:C_Small | Capacitor_SMD:C_0603_1608Metric_Pad1.05x0.95mm_HandSolder | ~
 |  | C531 | 1nF | Device:C_Small | Capacitor_SMD:C_0603_1608Metric_Pad1.05x0.95mm_HandSolder | ~
 |  | C532 | 220pF | Device:C_Small | Capacitor_SMD:C_0603_1608Metric_Pad1.05x0.95mm_HandSolder | ~
 |  | C533 | 220pF | Device:C_Small | Capacitor_SMD:C_0603_1608Metric_Pad1.05x0.95mm_HandSolder | ~
 |  | C534 | 1nF | Device:C_Small | Capacitor_SMD:C_0603_1608Metric_Pad1.05x0.95mm_HandSolder | ~
 |  | C535 | 39nF | Device:C_Small | Capacitor_SMD:C_0603_1608Metric_Pad1.05x0.95mm_HandSolder | ~
 |  | C536 | 2.7nF | Device:C_Small | Capacitor_SMD:C_0603_1608Metric_Pad1.05x0.95mm_HandSolder | ~
 |  | C537 | 2.7nF | Device:C_Small | Capacitor_SMD:C_0603_1608Metric_Pad1.05x0.95mm_HandSolder | ~
 |  | C538 | 10nF | Device:C_Small | Capacitor_SMD:C_0603_1608Metric_Pad1.05x0.95mm_HandSolder | ~
 |  | C539 | 0.1uF | Device:C_Small | Capacitor_SMD:C_0603_1608Metric_Pad1.05x0.95mm_HandSolder | ~
 |  | C540 | 10nF | Device:C_Small | Capacitor_SMD:C_0603_1608Metric_Pad1.05x0.95mm_HandSolder | ~
 |  | C541 | 100pF | Device:C_Small | Capacitor_SMD:C_0603_1608Metric_Pad1.05x0.95mm_HandSolder | ~
 |  | C542 | 100pF | Device:C_Small | Capacitor_SMD:C_0603_1608Metric_Pad1.05x0.95mm_HandSolder | ~
 |  | C543 | 10nF | Device:C_Small | Capacitor_SMD:C_0603_1608Metric_Pad1.05x0.95mm_HandSolder | ~
 |  | C544 | 0.1uF | Device:C_Small | Capacitor_SMD:C_0603_1608Metric_Pad1.05x0.95mm_HandSolder | ~
 |  | C545 | 10nF | Device:C_Small | Capacitor_SMD:C_0603_1608Metric_Pad1.05x0.95mm_HandSolder | ~
 |  | C546 | 4.7uF | Device:CP_Small | Capacitor_SMD:C_1206_3216Metric_Pad1.42x1.75mm_HandSolder | ~
 |  | C547 | 10nF | Device:C_Small | Capacitor_SMD:C_0603_1608Metric_Pad1.05x0.95mm_HandSolder | ~
 |  | C548 | 0.1uF | Device:C_Small | Capacitor_SMD:C_0603_1608Metric_Pad1.05x0.95mm_HandSolder | ~
 |  | C549 | 100pF | Device:C_Small | Capacitor_SMD:C_0603_1608Metric_Pad1.05x0.95mm_HandSolder | ~
 |  | C550 | 100pF | Device:C_Small | Capacitor_SMD:C_0603_1608Metric_Pad1.05x0.95mm_HandSolder | ~
 |  | D1 | LED | Device:LED | LED_SMD:LED_0805_2012Metric_Pad1.15x1.40mm_HandSolder | ~
 |  | D2 | LED | Device:LED | LED_SMD:LED_0805_2012Metric_Pad1.15x1.40mm_HandSolder | ~
 |  | J1 | USB_B_Mini | Connector:USB_B_Mini | Connector_USB:USB_Micro-B_Molex-105017-0001 | ~
 |  | J201 | Molex 73251-1150 SMA | Connector:Conn_Coaxial | Connector_Coaxial:SMA_Molex_73251-1153_EdgeMount_Horizontal | ~
 |  | J301 | Molex 73251-1150 SMA | Connector:Conn_Coaxial | Connector_Coaxial:SMA_Molex_73251-1153_EdgeMount_Horizontal | ~
 |  | J401 | Molex 73251-1150 SMA | Connector:Conn_Coaxial | Connector_Coaxial:SMA_Molex_73251-1153_EdgeMount_Horizontal | ~
 |  | J501 | Molex 73251-1150 SMA | Connector:Conn_Coaxial | Connector_Coaxial:SMA_Molex_73251-1153_EdgeMount_Horizontal | ~
 |  | L1 | 10uH | Device:L_Small | Inductor_SMD:L_Taiyo-Yuden_NR-60xx_HandSoldering | ~
 |  | L2 | 4.7uH | Device:L_Small | Inductor_SMD:L_0805_2012Metric_Pad1.15x1.40mm_HandSolder | ~
 |  | L3 | 4.7uH | Device:L_Small | Inductor_SMD:L_0805_2012Metric_Pad1.15x1.40mm_HandSolder | ~
 |  | L4 | 10uH | Device:L_Small | Inductor_SMD:L_Taiyo-Yuden_NR-60xx_HandSoldering | ~
 |  | L201 | 150nH | Device:L_Small | Inductor_SMD:L_0603_1608Metric_Pad1.05x0.95mm_HandSolder | ~
 |  | L202 | 150nH | Device:L_Small | Inductor_SMD:L_0603_1608Metric_Pad1.05x0.95mm_HandSolder | ~
 |  | L301 | 150nH | Device:L_Small | Inductor_SMD:L_0603_1608Metric_Pad1.05x0.95mm_HandSolder | ~
 |  | L302 | 150nH | Device:L_Small | Inductor_SMD:L_0603_1608Metric_Pad1.05x0.95mm_HandSolder | ~
 |  | L401 | 150nH | Device:L_Small | Inductor_SMD:L_0603_1608Metric_Pad1.05x0.95mm_HandSolder | ~
 |  | L402 | 150nH | Device:L_Small | Inductor_SMD:L_0603_1608Metric_Pad1.05x0.95mm_HandSolder | ~
 |  | L501 | 150nH | Device:L_Small | Inductor_SMD:L_0603_1608Metric_Pad1.05x0.95mm_HandSolder | ~
 |  | L502 | 150nH | Device:L_Small | Inductor_SMD:L_0603_1608Metric_Pad1.05x0.95mm_HandSolder | ~
 |  | R1 | 25 | Device:R_Small | Resistor_SMD:R_0603_1608Metric_Pad1.05x0.95mm_HandSolder | ~
 |  | R2 | 25 | Device:R_Small | Resistor_SMD:R_0603_1608Metric_Pad1.05x0.95mm_HandSolder | ~
 |  | R3 | 25 | Device:R_Small | Resistor_SMD:R_0603_1608Metric_Pad1.05x0.95mm_HandSolder | ~
 |  | R4 | 25 | Device:R_Small | Resistor_SMD:R_0603_1608Metric_Pad1.05x0.95mm_HandSolder | ~
 |  | R5 | 0 | Device:R_Small | Resistor_SMD:R_0603_1608Metric_Pad1.05x0.95mm_HandSolder | ~
 |  | R6 | 20k | Device:R_Small | Resistor_SMD:R_0603_1608Metric_Pad1.05x0.95mm_HandSolder | ~
 |  | R7 | 1k | Device:R_Small | Resistor_SMD:R_0603_1608Metric_Pad1.05x0.95mm_HandSolder | ~
 |  | R8 | 1k | Device:R_Small | Resistor_SMD:R_0603_1608Metric_Pad1.05x0.95mm_HandSolder | ~
 |  | R9 | 2.2k | Device:R_Small | Resistor_SMD:R_0603_1608Metric_Pad1.05x0.95mm_HandSolder | ~
 |  | R10 | 2.2k | Device:R_Small | Resistor_SMD:R_0603_1608Metric_Pad1.05x0.95mm_HandSolder | ~
 |  | R201 | 25 | Device:R_Small | Resistor_SMD:R_0603_1608Metric_Pad1.05x0.95mm_HandSolder | ~
 |  | R202 | 0 | Device:R_Small | Resistor_SMD:R_0603_1608Metric_Pad1.05x0.95mm_HandSolder | ~
 |  | R203 | 0 | Device:R_Small | Resistor_SMD:R_0603_1608Metric_Pad1.05x0.95mm_HandSolder | ~
 |  | R204 | 0 | Device:R_Small | Resistor_SMD:R_0603_1608Metric_Pad1.05x0.95mm_HandSolder | ~
 |  | R205 | 25 | Device:R_Small | Resistor_SMD:R_0603_1608Metric_Pad1.05x0.95mm_HandSolder | ~
 |  | R206 | 25 | Device:R_Small | Resistor_SMD:R_0603_1608Metric_Pad1.05x0.95mm_HandSolder | ~
 |  | R207 | 0 | Device:R_Small | Resistor_SMD:R_0603_1608Metric_Pad1.05x0.95mm_HandSolder | ~
 |  | R208 | 0 | Device:R_Small | Resistor_SMD:R_0603_1608Metric_Pad1.05x0.95mm_HandSolder | ~
 |  | R209 | 50 | Device:R_Small | Resistor_SMD:R_0603_1608Metric_Pad1.05x0.95mm_HandSolder | ~
 |  | R210 | 0 | Device:R_Small | Resistor_SMD:R_0603_1608Metric_Pad1.05x0.95mm_HandSolder | ~
 |  | R211 | 0 | Device:R_Small | Resistor_SMD:R_0603_1608Metric_Pad1.05x0.95mm_HandSolder | ~
 |  | R212 | 0 | Device:R_Small | Resistor_SMD:R_0603_1608Metric_Pad1.05x0.95mm_HandSolder | ~
 |  | R213 | 0 | Device:R_Small | Resistor_SMD:R_0603_1608Metric_Pad1.05x0.95mm_HandSolder | ~
 |  | R214 | 0 | Device:R_Small | Resistor_SMD:R_0603_1608Metric_Pad1.05x0.95mm_HandSolder | ~
 |  | R215 | 0 | Device:R_Small | Resistor_SMD:R_0603_1608Metric_Pad1.05x0.95mm_HandSolder | ~
 |  | R216 | 0 | Device:R_Small | Resistor_SMD:R_0603_1608Metric_Pad1.05x0.95mm_HandSolder | ~
 |  | R217 | 50 | Device:R_Small | Resistor_SMD:R_0603_1608Metric_Pad1.05x0.95mm_HandSolder | ~
 |  | R218 | 0 | Device:R_Small | Resistor_SMD:R_0603_1608Metric_Pad1.05x0.95mm_HandSolder | ~
 |  | R219 | 0 | Device:R_Small | Resistor_SMD:R_0603_1608Metric_Pad1.05x0.95mm_HandSolder | ~
 |  | R220 | 0 | Device:R_Small | Resistor_SMD:R_0603_1608Metric_Pad1.05x0.95mm_HandSolder | ~
 |  | R221 | 0 | Device:R_Small | Resistor_SMD:R_0603_1608Metric_Pad1.05x0.95mm_HandSolder | ~
 |  | R222 | 0 | Device:R_Small | Resistor_SMD:R_0603_1608Metric_Pad1.05x0.95mm_HandSolder | ~
 |  | R223 | 0 | Device:R_Small | Resistor_SMD:R_0603_1608Metric_Pad1.05x0.95mm_HandSolder | ~
 |  | R224 | 0 | Device:R_Small | Resistor_SMD:R_0603_1608Metric_Pad1.05x0.95mm_HandSolder | ~
 |  | R225 | 0 | Device:R_Small | Resistor_SMD:R_0603_1608Metric_Pad1.05x0.95mm_HandSolder | ~
 |  | R226 | 0 | Device:R_Small | Resistor_SMD:R_0603_1608Metric_Pad1.05x0.95mm_HandSolder | ~
 |  | R227 | 0 | Device:R_Small | Resistor_SMD:R_0603_1608Metric_Pad1.05x0.95mm_HandSolder | ~
 |  | R228 | 0 | Device:R_Small | Resistor_SMD:R_0603_1608Metric_Pad1.05x0.95mm_HandSolder | ~
 |  | R229 | 0 | Device:R_Small | Resistor_SMD:R_0603_1608Metric_Pad1.05x0.95mm_HandSolder | ~
 |  | R230 | 0 | Device:R_Small | Resistor_SMD:R_0603_1608Metric_Pad1.05x0.95mm_HandSolder | ~
 |  | R231 | 0 | Device:R_Small | Resistor_SMD:R_0603_1608Metric_Pad1.05x0.95mm_HandSolder | ~
 |  | R232 | 0 | Device:R_Small | Resistor_SMD:R_0603_1608Metric_Pad1.05x0.95mm_HandSolder | ~
 |  | R233 | 0 | Device:R_Small | Resistor_SMD:R_0603_1608Metric_Pad1.05x0.95mm_HandSolder | ~
 |  | R234 | 499R | Device:R_Small | Resistor_SMD:R_0603_1608Metric_Pad1.05x0.95mm_HandSolder | ~
 |  | R235 | 360R | Device:R_Small | Resistor_SMD:R_0603_1608Metric_Pad1.05x0.95mm_HandSolder | ~
 |  | R236 | 0R | Device:R_Small | Resistor_SMD:R_0603_1608Metric_Pad1.05x0.95mm_HandSolder | ~
 |  | R237 | 20k | Device:R_Small | Resistor_SMD:R_0603_1608Metric_Pad1.05x0.95mm_HandSolder | ~
 |  | R238 | 0R | Device:R_Small | Resistor_SMD:R_0603_1608Metric_Pad1.05x0.95mm_HandSolder | ~
 |  | R239 | 40.2k | Device:R_Small | Resistor_SMD:R_0603_1608Metric_Pad1.05x0.95mm_HandSolder | ~
 |  | R240 | 10k | Device:R_Small | Resistor_SMD:R_0603_1608Metric_Pad1.05x0.95mm_HandSolder | ~
 |  | R241 | 0R | Device:R_Small | Resistor_SMD:R_0603_1608Metric_Pad1.05x0.95mm_HandSolder | ~
 |  | R242 | 20k | Device:R_Small | Resistor_SMD:R_0603_1608Metric_Pad1.05x0.95mm_HandSolder | ~
 |  | R243 | 0R | Device:R_Small | Resistor_SMD:R_0603_1608Metric_Pad1.05x0.95mm_HandSolder | ~
 |  | R244 | 40.2k | Device:R_Small | Resistor_SMD:R_0603_1608Metric_Pad1.05x0.95mm_HandSolder | ~
 |  | R245 | 10k | Device:R_Small | Resistor_SMD:R_0603_1608Metric_Pad1.05x0.95mm_HandSolder | ~
 |  | R246 | 0R | Device:R_Small | Resistor_SMD:R_0603_1608Metric_Pad1.05x0.95mm_HandSolder | ~
 |  | R301 | 25 | Device:R_Small | Resistor_SMD:R_0603_1608Metric_Pad1.05x0.95mm_HandSolder | ~
 |  | R302 | 0 | Device:R_Small | Resistor_SMD:R_0603_1608Metric_Pad1.05x0.95mm_HandSolder | ~
 |  | R303 | 0 | Device:R_Small | Resistor_SMD:R_0603_1608Metric_Pad1.05x0.95mm_HandSolder | ~
 |  | R304 | 0 | Device:R_Small | Resistor_SMD:R_0603_1608Metric_Pad1.05x0.95mm_HandSolder | ~
 |  | R305 | 25 | Device:R_Small | Resistor_SMD:R_0603_1608Metric_Pad1.05x0.95mm_HandSolder | ~
 |  | R306 | 25 | Device:R_Small | Resistor_SMD:R_0603_1608Metric_Pad1.05x0.95mm_HandSolder | ~
 |  | R307 | 0 | Device:R_Small | Resistor_SMD:R_0603_1608Metric_Pad1.05x0.95mm_HandSolder | ~
 |  | R308 | 0 | Device:R_Small | Resistor_SMD:R_0603_1608Metric_Pad1.05x0.95mm_HandSolder | ~
 |  | R309 | 50 | Device:R_Small | Resistor_SMD:R_0603_1608Metric_Pad1.05x0.95mm_HandSolder | ~
 |  | R310 | 0 | Device:R_Small | Resistor_SMD:R_0603_1608Metric_Pad1.05x0.95mm_HandSolder | ~
 |  | R311 | 0 | Device:R_Small | Resistor_SMD:R_0603_1608Metric_Pad1.05x0.95mm_HandSolder | ~
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

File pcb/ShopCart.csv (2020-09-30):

Line No. | Order Code | RoHS Compliant? | Your Part No | Notes | Qty | Manufacturer Part Number | Manufacturer Name | Manufacturer / Description | Availability | Unit Price (excl GST) | Line Price (excl GST) | Discount Price
1 | 1710167 | RoHS: YES / PHTHALATES: YES |  |  | 60.0 | MC0603N101K500CT | MULTICOMP PRO | MULTICOMP PRO CERAMIC CAPACITOR 100PF 50V, C0G, 10%, 0603 | 54965 | 0.0140 | 0.84
2 | 1759016 | RoHS: YES / PHTHALATES: YES |  |  | 50.0 | MC0603B104K160CT | MULTICOMP PRO | MULTICOMP PRO SMD Multilayer Ceramic Capacitor, 0.1 µF, 16 V, 0603 [1608 Metric], ± 10%, X7R, MC Series | 29738 | 0.0210 | 1.05
3 | 2812090 | RoHS: YES / PHTHALATES: YES |  |  | 50.0 | 885012006010 | WURTH ELEKTRONIK | WURTH ELEKTRONIK SMD Multilayer Ceramic Capacitor, 220 pF, 10 V, 0603 [1608 Metric], ± 5%, C0G / NP0 | 3410 | 0.0440 | 2.20
4 | 1759030 | RoHS: YES / PHTHALATES: YES |  |  | 10.0 | MC0603B393K250CT | MULTICOMP PRO | MULTICOMP PRO SMD Multilayer Ceramic Capacitor, 39000 pF, 25 V, 0603 [1608 Metric], ± 10%, X7R, MC Series | 4000 | 0.0240 | 0.24
5 | 2310322 | RoHS: YES / PHTHALATES: YES |  |  | 10.0 | MCHH18N101G500CT | MULTICOMP PRO | MULTICOMP PRO Capacitor, RF, Low ESR, 100 pF, 50 V, MCHH Series, ± 2%, 125 °C, 0603 [1608 Metric] | 3304 | 0.1890 | 1.89
6 | 244774301 | RoHS: Y-EX / PHTHALATES: YES |  |  | 200.0 | MCWR06X000 PTL | MULTICOMP PRO | MULTICOMP PRO SMD Chip Resistor, Jumper, 0 ohm, 100 mW, 0603 [1608 Metric], Thick Film, General Purpose | 81310 | 0.0030 | 0.60
7 | 244723001 | RoHS: Y-EX / PHTHALATES: YES |  |  | 30.0 | MCWR06X1002FTL | MULTICOMP PRO | MULTICOMP PRO SMD Chip Resistor, 10 kohm, ± 1%, 100 mW, 0603 [1608 Metric], Thick Film, General Purpose | 402679 | 0.0030 | 0.09
8 | 2447293 | RoHS: Y-EX / PHTHALATES: YES |  |  | 40.0 | MCWR06X2002FTL | MULTICOMP PRO | MULTICOMP PRO SMD Chip Resistor, 20 kohm, ± 1%, 100 mW, 0603 [1608 Metric], Thick Film, General Purpose | 36769 | 0.0040 | 0.16
9 | 1909295 | RoHS: YES / PHTHALATES: YES |  |  | 4.0 | 73251-1150 | MOLEX | MOLEX RF / Coaxial Connector, SMA Coaxial, Straight Jack, Board Edge / End Launch, 50 ohm | 1091 | 5.3000 | 21.20
10 | 2447311 | RoHS: Y-EX / PHTHALATES: YES |  |  | 50.0 | MCWR06X24R9FTL | MULTICOMP PRO | MULTICOMP PRO SMD Chip Resistor, 24.9 ohm, ± 1%, 100 mW, 0603 [1608 Metric], Thick Film, General Purpose | 220 | 0.0040 | 0.20
11 | 2112878 | RoHS: Y-EX / PHTHALATES: YES |  |  | 30.0 | CRCW060350R0FKEA | VISHAY | VISHAY SMD Chip Resistor, 50 ohm, ± 1%, 100 mW, 0603 [1608 Metric], Thick Film, General Purpose | 700066 Available until stock is exhausted | 0.0070 | 0.21
12 | 2447348 | RoHS: Y-EX / PHTHALATES: YES |  |  | 20.0 | MCWR06X3600FTL | MULTICOMP PRO | MULTICOMP PRO SMD Chip Resistor, 360 ohm, ± 1%, 100 mW, 0603 [1608 Metric], Thick Film, General Purpose | 22528 | 0.0040 | 0.08
13 | 2776084 | RoHS: YES / PHTHALATES: YES |  |  | 5.0 | BGA2803,115 | NXP | NXP RF Amplifier, 22.6 dB Gain / 3.4 dB Noise, DC to 2.2 GHz, 2.7 V to 3.3 V Supply, SOT-363-6 | 538 | 0.2660 | 1.33
14 | 3370589 | RoHS: YES / PHTHALATES: YES |  |  | 10.0 | MP002923 | MULTICOMP PRO | MULTICOMP PRO High Frequency Inductor, 150 nH, 200 mA, 0603 [1608 Metric], Multilayer, 1.6 ohm | 4000 | 0.0940 | 0.94
15 | 1865512 | RoHS: YES / PHTHALATES: YES |  |  | 20.0 | C0603C272J1GACTU | KEMET | KEMET SMD Multilayer Ceramic Capacitor, 2700 pF, 100 V, 0603 [1608 Metric], ± 5%, C0G / NP0 | 1390 | 0.0260 | 0.52
16 | 2280661RL | RoHS: YES / PHTHALATES: YES |  |  | 150.0 | 0603YC103KAT2A | AVX | AVX SMD Multilayer Ceramic Capacitor, 10000 pF, 16 V, 0603 [1608 Metric], ± 10%, X7R, AVX 0603 MLCC | 21668 | 0.0030 | 0.45
17 | 2812094 | RoHS: YES / PHTHALATES: YES |  |  | 10.0 | 885012006017 | WURTH ELEKTRONIK | WURTH ELEKTRONIK SMD Multilayer Ceramic Capacitor, 10 pF, 16 V, 0603 [1608 Metric], ± 5%, C0G / NP0 | 4902 | 0.0360 | 0.36
18 | 261495001 | RoHS: YES / PHTHALATES: YES |  |  | 10.0 | 105017-1001 | MOLEX | MOLEX USB Connector, Micro USB Type B, USB 2.0, Receptacle, 5 Ways, Surface Mount, Right Angle | 5705 | 0.4040 | 4.04
19 | 2533832 | RoHS: YES / PHTHALATES: YES |  |  | 30.0 | 885012006029 | WURTH ELEKTRONIK | WURTH ELEKTRONIK SMD Multilayer Ceramic Capacitor, 1000 pF, 16 V, 0603 [1608 Metric], ± 5%, C0G / NP0 | 2710 | 0.0520 | 1.56
20 | 1432350 | RoHS: YES / PHTHALATES: YES |  |  | 12.0 | TAJA475K006RNJ | AVX | AVX Surface Mount Tantalum Capacitor, 4.7 µF, 6.3 V, 1206 [3216 Metric], TAJ Series, ± 10%, -55 °C | 2575 | 0.1090 | 1.31
21 | 1312827 | RoHS: YES / PHTHALATES: TBA |  |  | 6.0 | LMV712MM | TEXAS INSTRUMENTS | TEXAS INSTRUMENTS Operational Amplifier, Dual, 2 Amplifier, 5 MHz, 5 V/µs, 2.7V to 5.5V, MSOP, 10 Pins | 170 Available until stock is exhausted | 0.5830 | 3.50
22 | 3019512 | RoHS: YES / PHTHALATES: YES |  |  | 20.0 | CC0603JRNPO9BN391 | YAGEO | YAGEO SMD Multilayer Ceramic Capacitor, 390 pF, 50 V, 0603 [1608 Metric], ± 5%, C0G / NP0, CC Series | 1243 | 0.1010 | 2.02
23 | 244727201 | RoHS: Y-EX / PHTHALATES: YES |  |  | 20.0 | MCWR06X1001FTL | MULTICOMP PRO | MULTICOMP PRO SMD Chip Resistor, 1 kohm, ± 1%, 100 mW, 0603 [1608 Metric], Thick Film, General Purpose | 121681 | 0.0030 | 0.06
24 | 2694886 | RoHS: YES / PHTHALATES: YES |  |  | 20.0 | MCWR06X4990FTL | MULTICOMP PRO | MULTICOMP PRO SMD Chip Resistor, 499 ohm, ± 1%, 100 mW, 0603 [1608 Metric], Thick Film, General Purpose | 13030 | 0.0040 | 0.08
25 | 2447368 | RoHS: Y-EX / PHTHALATES: YES |  |  | 30.0 | MCWR06X4022FTL | MULTICOMP PRO | MULTICOMP PRO SMD Chip Resistor, 40.2 kohm, ± 1%, 100 mW, 0603 [1608 Metric], Thick Film, General Purpose | 6639 | 0.0040 | 0.12
26 | 9527699 | RoHS: YES / PHTHALATES: TBA |  |  | 20.0 | GRM188R60J105KA01D | MURATA | MURATA SMD Multilayer Ceramic Capacitor, 1 µF, 6.3 V, 0603 [1608 Metric], ± 10%, X5R, GRM Series | 5125 Available until stock is exhausted | 0.0120 | 0.24
27 | 244732001 | RoHS: Y-EX / PHTHALATES: YES |  |  | 20.0 | MCWR06X2201FTL | MULTICOMP PRO | MULTICOMP PRO SMD Chip Resistor, 2.2 kohm, ± 1%, 100 mW, 0603 [1608 Metric], Thick Film, General Purpose | 46980 | 0.0030 | 0.06
28 | 2888491 | RoHS: YES / PHTHALATES: YES |  |  | 12.0 | MAX19777AZA+ | MAXIM INTEGRATED PRODUCTS | MAXIM INTEGRATED PRODUCTS Analogue to Digital Converter, 12 bit, 3 MSPS, Differential, Single Ended, Microwire, QSPI, SPI | 635 | 2.2300 | 26.76
29 | 1296574 | RoHS: YES / PHTHALATES: YES |  |  | 1.0 | 24LC128T-I/SN | MICROCHIP | MICROCHIP EEPROM, 128 Kbit, 16K x 8bit, Serial I2C (2-Wire), 400 kHz, SOIC, 8 Pins | 3209 | 0.7580 | 0.76
30 | 1269406 | RoHS: YES / PHTHALATES: YES |  |  | 5.0 | USBLC6-2SC6 | STMICROELECTRONICS | STMICROELECTRONICS ESD Protection Device, 17 V, SOT-23, 6 Pins, 6 V, 85 W, USBLC Series | 30621 | 0.5200 | 2.60
31 | 1269134 | RoHS: YES / PHTHALATES: YES |  |  | 1.0 | CY7C68013A-56PVXC | CYPRESS SEMICONDUCTOR | CYPRESS SEMICONDUCTOR MCU-Application Specific 8BIT, 8051, 48MHz, 16 KB RAM, 3V-3.6Vin, SSOP-56 | 1786 | 16.0800 | 16.08
32 | 1578404 | RoHS: YES / PHTHALATES: YES |  |  | 1.0 | MCP1825S-3302E/DB | MICROCHIP | MICROCHIP Fixed LDO Voltage Regulator, 2.1V to 6V, 210mV Dropout, 3.3Vout, 500mAout, SOT-223-3 | 10457 | 0.7140 | 0.71
33 | 2101848 | RoHS: YES / PHTHALATES: YES |  |  | 2.0 | NB3L553DG | ON SEMICONDUCTOR | ON SEMICONDUCTOR Clock Fanout Buffer, 200 MHz, 1:4, 2.5 V / 3.3 V / 5.0 V, SOIC-8 | 273 | 1.4100 | 2.82
34 | 1904340 | RoHS: YES / PHTHALATES: YES |  |  | 4.0 | BRC2012T4R7MD | TAIYO YUDEN | TAIYO YUDEN INDUCTOR, 4.7UH, 600MA, 20%, 250MHZ | 1429 | 0.4340 | 1.74
35 | 2325488 | RoHS: YES / PHTHALATES: YES |  |  | 2.0 | 7Q-24.000MBN-T | TXC | TXC TCXO, GPS, 24MHZ, 3.2 X 2.5MM, CLIPPED SINE | 1608 | 2.5900 | 5.18
36 | 249423301 | RoHS: YES / PHTHALATES: YES |  |  | 10.0 | GRM188R61A106KE69D | MURATA | MURATA SMD Multilayer Ceramic Capacitor, 10 µF, 10 V, 0603 [1608 Metric], ± 10%, X5R, GRM Series | 119194 | 0.1160 | 1.16
37 | 2428234 | RoHS: YES / PHTHALATES: YES |  |  | 2.0 | SRN5040-100M | BOURNS | BOURNS Power Inductor (SMD), 10 µH, 2.1 A, Semishielded, 2.3 A, SRN5040 Series, 5mm x 5mm x 4mm | 598 | 0.1690 | 0.34
38 | 2096000 | RoHS: YES / PHTHALATES: YES |  |  | 1.0 | 7Q-26.000MBN-T | TXC | TXC TCXO, GPS, 26MHZ, 3.2 X 2.5MM, CLIPPED SINE | 2107 | 2.5900 | 2.59
39 | 2058006 | RoHS: YES / PHTHALATES: YES |  |  | 1.0 | FOXSDLF/240F-20. | FOX ELECTRONICS | FOX ELECTRONICS CRYSTAL, 24MHZ, 20PF, HC-49S | 3 | 0.3640 | 0.36
40 | 3004369 | RoHS: YES / PHTHALATES: YES |  |  | 2.0 | ADS7883SDBVT | TEXAS INSTRUMENTS | TEXAS INSTRUMENTS Analogue to Digital Converter, 12 bit, 3 MSPS, Single Ended, SPI, Single, 2.7 V | 710 | 8.4900 | 16.98
 |  |  |  |  |  |  | Sub Total | 123.43
 |  |  |  |  |  |  | Goods Total | 123.43
 |  |  |  |  |  |  | Delivery | 0.00
 |  |  |  |  |  |  | GST | 12.34
 |  |  |  |  |  |  | Total | 135.77

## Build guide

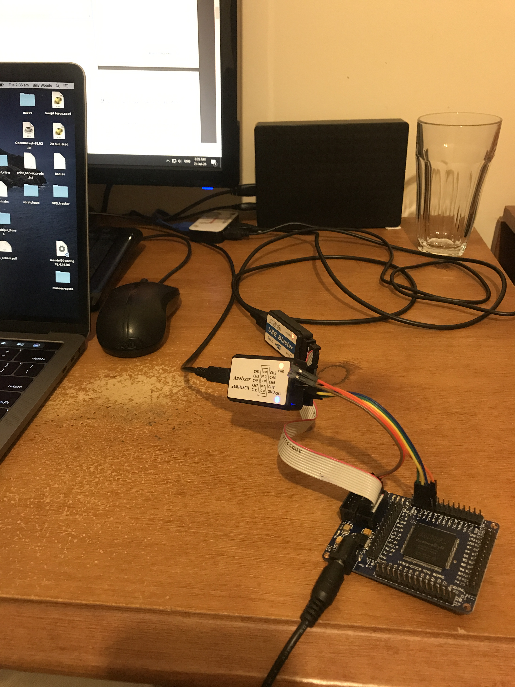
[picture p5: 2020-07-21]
experiments/FPGA_SPI_slave_results/setup.JPG

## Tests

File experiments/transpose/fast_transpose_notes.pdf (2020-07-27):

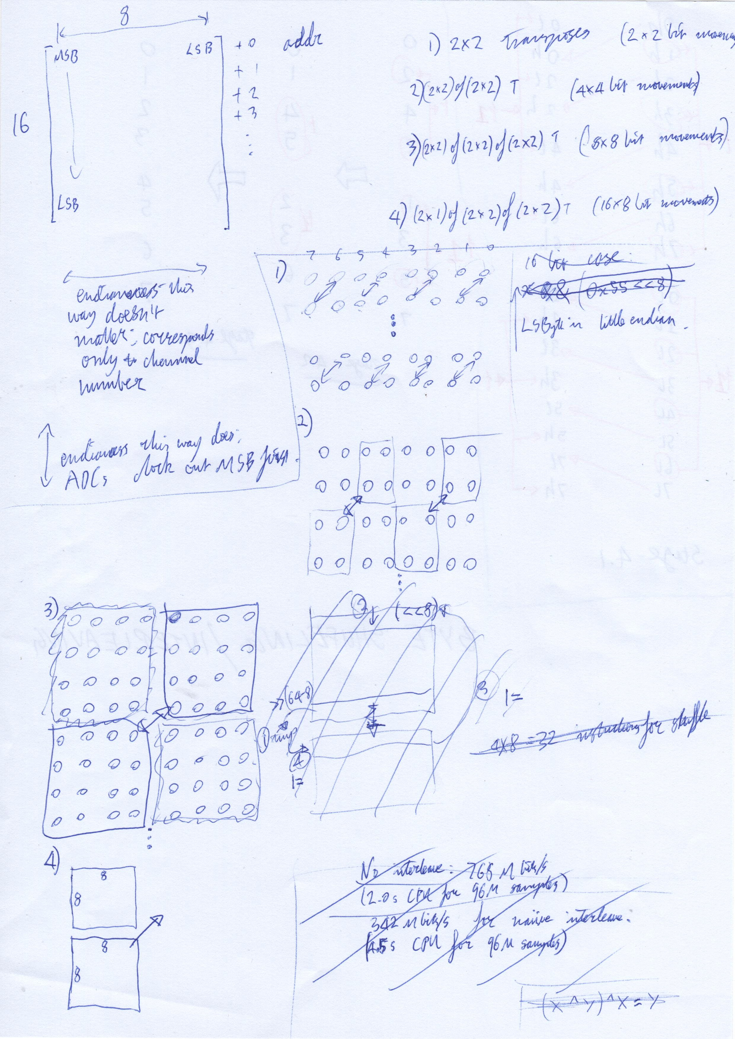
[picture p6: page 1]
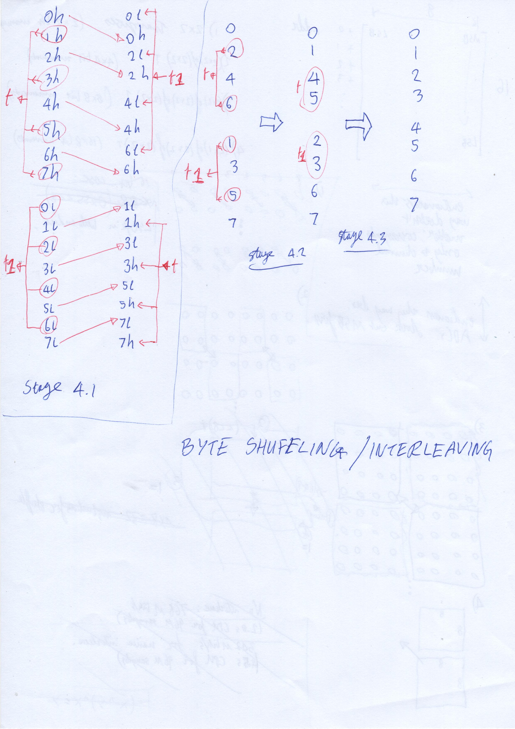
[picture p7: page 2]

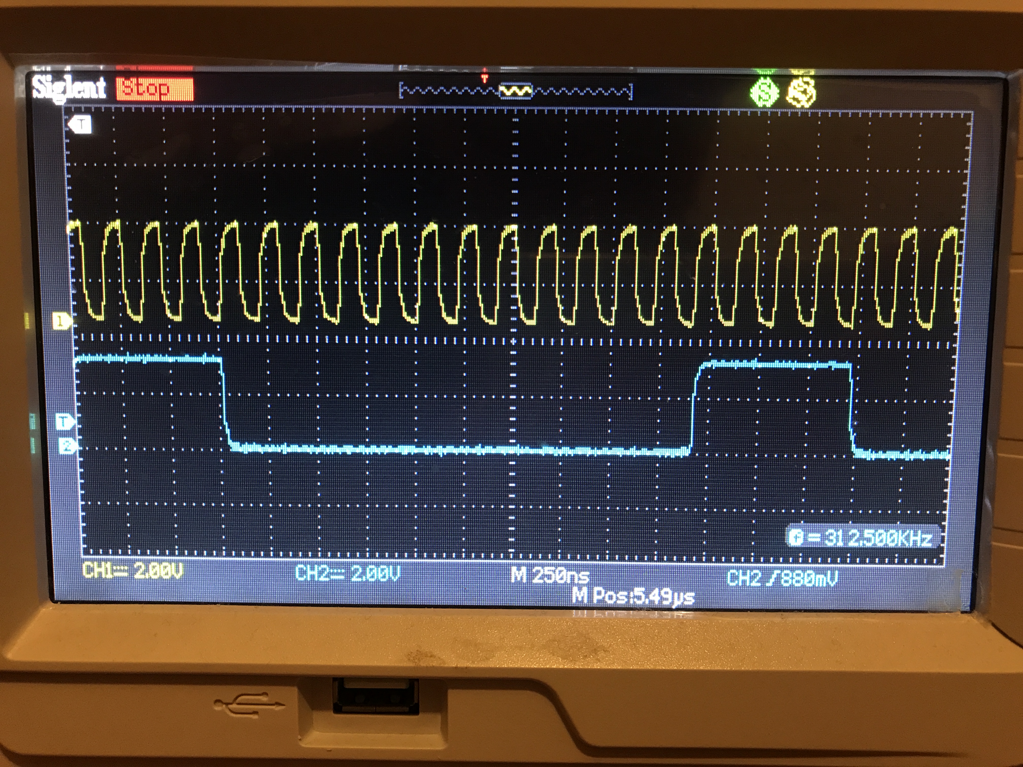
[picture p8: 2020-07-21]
experiments/FPGA_SPI_slave_results/clk and cs.JPG

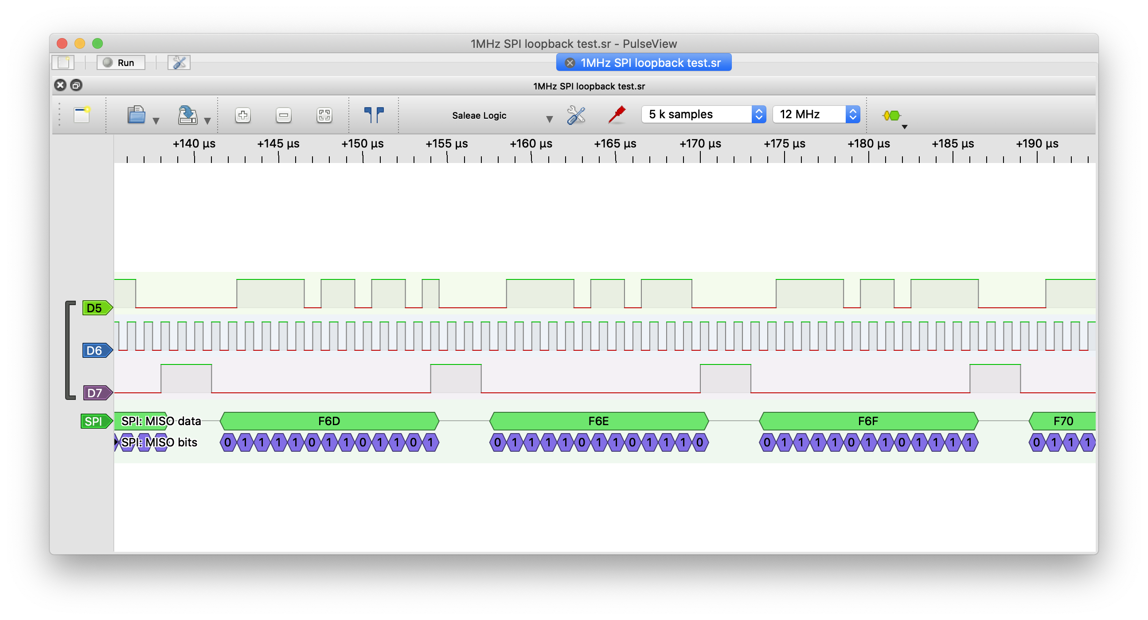
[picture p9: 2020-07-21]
experiments/FPGA_SPI_slave_results/Screen Shot 2020-07-21 at 2.32.01 am.png

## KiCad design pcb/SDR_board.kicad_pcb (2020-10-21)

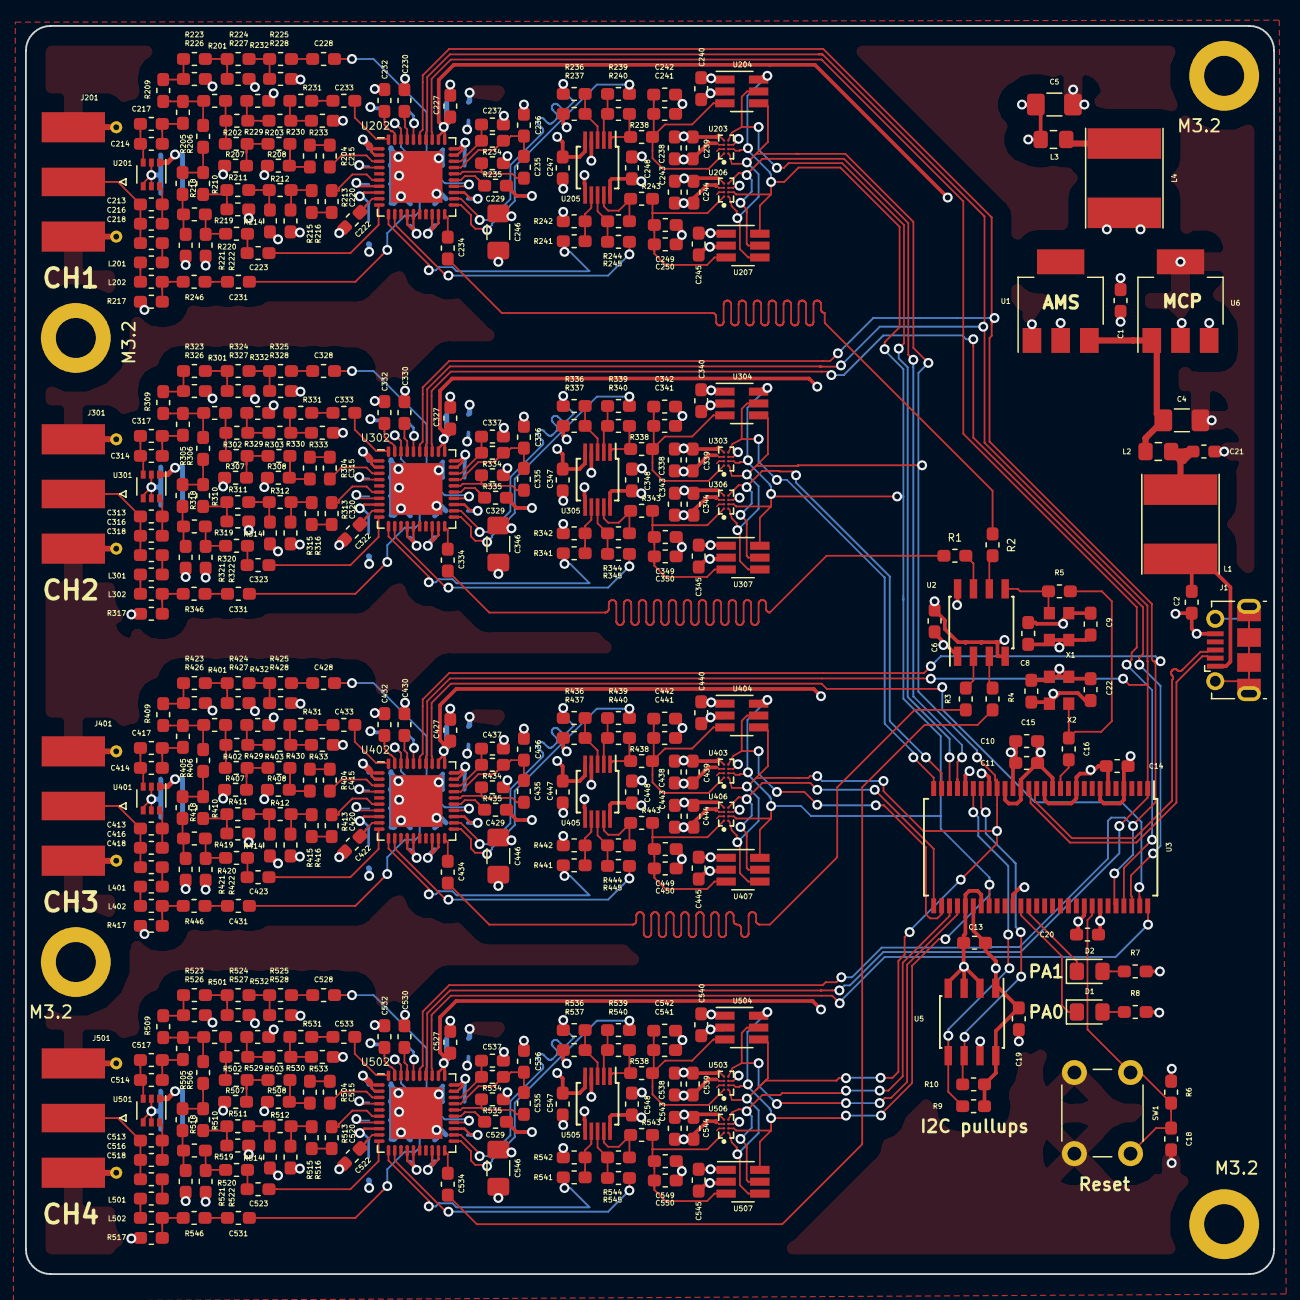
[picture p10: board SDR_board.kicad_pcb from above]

Board: 4 copper layers, 100.0 x 100.0 mm, 467 parts (0 on the bottom side), 267 nets.

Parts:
C1, C2, C21, C226, C326, C426, C526: 1uF; C_0603_1608Metric_Pad1.05x0.95mm_HandSolder
C4, C5, C246, C346, C446, C546: 4.7uF; C_1206_3216Metric_Pad1.42x1.75mm_HandSolder
C6, C9, C15, C16, C230, C231, C234, C330, C331, C334, C430, C431, C434, C530, C531, C534: 1nF; C_0603_1608Metric_Pad1.05x0.95mm_HandSolder
C8, C10, C13, C14, C18, C20, C22, C201, C202, C218, C225, C239, C244, C248, C301, C302, C318, C325, C339, C344, C348, C401, C402, C418, C425, C439, C444, C448, C501, C502, C518, C525, C539, C544, C548: 0.1uF; C_0603_1608Metric_Pad1.05x0.95mm_HandSolder
C11, C19, C210, C212, C227, C238, C240, C243, C245, C247, C310, C312, C327, C338, C340, C343, C345, C347, C410, C412, C427, C438, C440, C443, C445, C447, C510, C512, C527, C538, C540, C543, C545, C547: 10nF; C_0603_1608Metric_Pad1.05x0.95mm_HandSolder
C203, C204, C205, C206, C207, C208, C209, C211, C213, C214, C216, C217, C228, C229, C241, C242, C249, C250, C303, C304, C305, C306, C307, C308, C309, C311, C313, C314, C316, C317, C328, C329, C341, C342, C349, C350, C403, C404, C405, C406, C407, C408, C409, C411, C413, C414, C416, C417, C428, C429, C441, C442, C449, C450, C503, C504, C505, C506, C507, C508, C509, C511, C513, C514, C516, C517, C528, C529, C541, C542, C549, C550: 100pF; C_0603_1608Metric_Pad1.05x0.95mm_HandSolder
C215, C219, C220, C221, C232, C233, C315, C319, C320, C321, C332, C333, C415, C419, C420, C421, C432, C433, C515, C519, C520, C521, C532, C533: 220pF; C_0603_1608Metric_Pad1.05x0.95mm_HandSolder
C222, C223, C322, C323, C422, C423, C522, C523: 390pF; C_0603_1608Metric_Pad1.05x0.95mm_HandSolder
C235, C335, C435, C535: 39nF; C_0603_1608Metric_Pad1.05x0.95mm_HandSolder
C236, C237, C336, C337, C436, C437, C536, C537: 2.7nF; C_0603_1608Metric_Pad1.05x0.95mm_HandSolder
D1, D2: LED; LED_0805_2012Metric_Pad1.15x1.40mm_HandSolder
J1: USB_B_Mini; USB_Micro-B_Molex-105017-0001
J201, J301, J401, J501: Molex 73251-1150 SMA; SMA_Molex_73251-1153_EdgeMount_Horizontal
L1, L4: 10uH; L_Taiyo-Yuden_NR-60xx_HandSoldering
L2, L3: 4.7uH; L_0805_2012Metric_Pad1.15x1.40mm_HandSolder
L201, L202, L301, L302, L401, L402, L501, L502: 150nH; L_0603_1608Metric_Pad1.05x0.95mm_HandSolder
M3.2, M3.2#2, M3.2#3, M3.2#4: MountingHole_3.2mm_M3_DIN965_Pad
R1, R2, R3, R4, R201, R205, R206, R301, R305, R306, R401, R405, R406, R501, R505, R506: 25; R_0603_1608Metric_Pad1.05x0.95mm_HandSolder
R5, R202, R203, R204, R207, R208, R210, R211, R212, R213, R214, R215, R216, R218, R219, R220, R221, R222, R223, R224, R225, R226, R227, R228, R229, R230, R231, R232, R233, R302, R303, R304, R307, R308, R310, R311, R312, R313, R314, R315, R316, R318, R319, R320, R321, R322, R323, R324, R325, R326, R327, R328, R329, R330, R331, R332, R333, R402, R403, R404, R407, R408, R410, R411, R412, R413, R414, R415, R416, R418, R419, R420, R421, R422, R423, R424, R425, R426, R427, R428, R429, R430, R431, R432, R433, R502, R503, R504, R507, R508, R510, R511, R512, R513, R514, R515, R516, R518, R519, R520, R521, R522, R523, R524, R525, R526, R527, R528, R529, R530, R531, R532, R533: 0; R_0603_1608Metric_Pad1.05x0.95mm_HandSolder
R6, R237, R242, R337, R342, R437, R442, R537, R542: 20k; R_0603_1608Metric_Pad1.05x0.95mm_HandSolder
R7, R8: 1k; R_0603_1608Metric_Pad1.05x0.95mm_HandSolder
R9, R10: 2.2k; R_0603_1608Metric_Pad1.05x0.95mm_HandSolder
R209, R217, R309, R317, R409, R417, R509, R517: 50; R_0603_1608Metric_Pad1.05x0.95mm_HandSolder
R234, R334, R434, R534: 499R; R_0603_1608Metric_Pad1.05x0.95mm_HandSolder
R235, R335, R435, R535: 360R; R_0603_1608Metric_Pad1.05x0.95mm_HandSolder
R236, R238, R241, R243, R246, R336, R338, R341, R343, R346, R436, R438, R441, R443, R446, R536, R538, R541, R543, R546: 0R; R_0603_1608Metric_Pad1.05x0.95mm_HandSolder
R239, R244, R339, R344, R439, R444, R539, R544: 40.2k; R_0603_1608Metric_Pad1.05x0.95mm_HandSolder
R240, R245, R340, R345, R440, R445, R540, R545: 10k; R_0603_1608Metric_Pad1.05x0.95mm_HandSolder
SW1: SW_Push; SW_PUSH_6mm_H5mm
U1: AMS1117-3.3; SOT-223
U2: NB3L553; SOIC-8_3.9x4.9mm_P1.27mm
U3: CY7C68013A-56PVX; SSOP-56_7.5x18.5mm_P0.635mm
U5: 24LC128; SOIC-8_3.9x4.9mm_P1.27mm
U6: MCP1825S; SOT-223-3_TabPin2
U201, U301, U401, U501: BGA2803; SOT-363_SC-70-6
U202, U302, U402, U502: MSi001-Q40; Texas_S-PVQFN-N40_EP4.15x4.15mm_less_solder_resist
U203, U206, U303, U306, U403, U406, U503, U506: MAX19777AZA+; BGA8N35P2X4_85X143X37N
U204, U207, U304, U307, U404, U407, U504, U507: ADS7883; SOT-23-6_Handsoldering
U205, U305, U405, U505: LMV712-N; MSOP-10_3x3mm_P0.5mm
X1, X2: XO32; Oscillator_SMD_EuroQuartz_XO32-4Pin_3.2x2.5mm

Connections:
+3.3VA: C5.1, C201.2, C202.2, C203.1, C204.1, C205.1, C206.1, C207.1, C208.1, C209.1, C210.1, C211.2, C212.1, C238.1, C239.2, C240.1, C243.1, C244.2, C245.1, C246.1, C247.1, C248.1, C301.2, C302.2, C303.1, C304.1, C305.1, C306.1, C307.1, C308.1, C309.1, C310.1, C311.2, C312.1, C338.1, C339.2, C340.1, C343.1, C344.2, C345.1, C346.1, C347.1, C348.1, C401.2, C402.2, C403.1, C404.1, C405.1, C406.1, C407.1, C408.1, C409.1, C410.1, C411.2, C412.1, C438.1, C439.2, C440.1, C443.1, C444.2, C445.1, C446.1, C447.1, C448.1, C501.2, C502.2, C503.1, C504.1, C505.1, C506.1, C507.1, C508.1, C509.1, C510.1, C511.2, C512.1, C538.1, C539.2, C540.1, C543.1, C544.2, C545.1, C546.1, C547.1, C548.1, L3.1, U201.1, U202.1, U202.2, U202.8, U202.14, U202.15, U202.18, U202.19, U202.23, U202.29, U202.30, U202.36, U203.A4, U204.1, U205.5, U205.6, U205.10, U206.A4, U207.1, U301.1, U302.1, U302.2, U302.8, U302.14, U302.15, U302.18, U302.19, U302.23, U302.29, U302.30, U302.36, U303.A4, U304.1, U305.5, U305.6, U305.10, U306.A4, U307.1, U401.1, U402.1, U402.2, U402.8, U402.14, U402.15, U402.18, U402.19, U402.23, U402.29, U402.30, U402.36, U403.A4, U404.1, U405.5, U405.6, U405.10, U406.A4, U407.1, U501.1, U502.1, U502.2, U502.8, U502.14, U502.15, U502.18, U502.19, U502.23, U502.29, U502.30, U502.36, U503.A4, U504.1, U505.5, U505.6, U505.10, U506.A4, U507.1
+3V3: C1.1, C6.1, C8.1, C9.1, C10.1, C11.1, C13.1, C14.1, C15.1, C19.1, C20.1, C22.1, C225.2, C226.2, C227.1, C325.2, C326.2, C327.1, C425.2, C426.2, C427.1, C525.2, C526.2, C527.1, L4.2, R6.1, R7.1, R8.1, R9.1, R10.1, U1.2, U2.1, U2.8, U3.6, U3.10, U3.14, U3.18, U3.24, U3.34, U3.39, U3.50, U5.1, U5.8, U6.3, U202.31, U202.32, U302.31, U302.32, U402.31, U402.32, U502.31, U502.32, X1.1, X1.4, X2.1, X2.4
/Channel 1/AM2_B3_MATCH: R201.1, R202.2, R229.2
/Channel 1/B45_VHF_MATCH: R206.1, R210.2, R218.2
/Channel 1/BUFFERED_SINGLE_I: C249.1, C250.1, R243.1, U206.A1, U207.3
/Channel 1/BUFFERED_SINGLE_Q: C241.1, C242.1, R238.1, U203.A1, U204.3
/Channel 1/I_DOUT: U3.25, U206.B4, U207.5
/Channel 1/I_N: R244.2, U202.12
/Channel 1/I_P: R241.2, U202.11
/Channel 1/L_MATCH: R209.1, R223.2, R226.2
/Channel 1/Q_DOUT: U3.26, U203.B4, U204.5
/Channel 1/Q_N: R239.2, U202.21
/Channel 1/Q_P: R236.2, U202.22
/Channel 1/high-Z: C231.2, R246.1
/Channel 2/AM2_B3_MATCH: R301.1, R302.2, R329.2
/Channel 2/B45_VHF_MATCH: R306.1, R310.2, R318.2
/Channel 2/BUFFERED_SINGLE_I: C349.1, C350.1, R343.1, U306.A1, U307.3
/Channel 2/BUFFERED_SINGLE_Q: C341.1, C342.1, R338.1, U303.A1, U304.3
/Channel 2/I_DOUT: U3.27, U306.B4, U307.5
/Channel 2/I_N: R344.2, U302.12
/Channel 2/I_P: R341.2, U302.11
/Channel 2/L_MATCH: R309.1, R323.2, R326.2
/Channel 2/Q_DOUT: U3.28, U303.B4, U304.5
/Channel 2/Q_N: R339.2, U302.21
/Channel 2/Q_P: R336.2, U302.22
/Channel 2/high-Z: C331.2, R346.1
/Channel 3/AM2_B3_MATCH: R401.1, R402.2, R429.2
/Channel 3/B45_VHF_MATCH: R406.1, R410.2, R418.2
/Channel 3/BUFFERED_SINGLE_I: C449.1, C450.1, R443.1, U406.A1, U407.3
/Channel 3/BUFFERED_SINGLE_Q: C441.1, C442.1, R438.1, U403.A1, U404.3
/Channel 3/I_DOUT: U3.29, U406.B4, U407.5
/Channel 3/I_N: R444.2, U402.12
/Channel 3/I_P: R441.2, U402.11
/Channel 3/L_MATCH: R409.1, R423.2, R426.2
/Channel 3/Q_DOUT: U3.30, U403.B4, U404.5
/Channel 3/Q_N: R439.2, U402.21
/Channel 3/Q_P: R436.2, U402.22
/Channel 3/high-Z: C431.2, R446.1
/Channel 4/AM2_B3_MATCH: R501.1, R502.2, R529.2
/Channel 4/B45_VHF_MATCH: R506.1, R510.2, R518.2
/Channel 4/BUFFERED_SINGLE_I: C549.1, C550.1, R543.1, U506.A1, U507.3
/Channel 4/BUFFERED_SINGLE_Q: C541.1, C542.1, R538.1, U503.A1, U504.3
/Channel 4/I_DOUT: U3.31, U506.B4, U507.5
/Channel 4/I_N: R544.2, U502.12
/Channel 4/I_P: R541.2, U502.11
/Channel 4/L_MATCH: R509.1, R523.2, R526.2
/Channel 4/Q_DOUT: U3.32, U503.B4, U504.5
/Channel 4/Q_N: R539.2, U502.21
/Channel 4/Q_P: R536.2, U502.22
/Channel 4/high-Z: C531.2, R546.1
/D_N: J1.2, U3.16
/D_P: J1.3, U3.15
/TUNER_1_CLK: C234.2, R2.2
/TUNER_1_nCS: U3.53, U202.33
/TUNER_2_CLK: C334.2, R1.2
/TUNER_2_nCS: U3.54, U302.33
/TUNER_3_CLK: C434.2, R3.1
/TUNER_3_nCS: U3.55, U402.33
/TUNER_4_CLK: C534.2, R4.1
/TUNER_4_nCS: U3.56, U502.33
ADC_CLK: U3.20, U203.B1, U204.4, U206.B1, U207.4, U303.B1, U304.4, U306.B1, U307.4, U403.B1, U404.4, U406.B1, U407.4, U503.B1, U504.4, U506.B1, U507.4
ADC_nCS: U3.36, U203.B2, U204.6, U206.B2, U207.6, U303.B2, U304.6, U306.B2, U307.6, U403.B2, U404.6, U406.B2, U407.6, U503.B2, U504.6, U506.B2, U507.6
FX2LP_AUX_OSC: C16.1, R5.1, X2.3
GND: C1.2, C2.2, C4.2, C5.2, C6.2, C8.2, C9.2, C10.2, C11.2, C13.2, C14.2, C15.2, C18.2, C19.2, C20.2, C21.2, C22.2, C201.1, C202.1, C203.2, C204.2, C205.2, C206.2, C207.2, C208.2, C209.2, C210.2, C211.1, C212.2, C219.2, C221.2, C222.2, C225.1, C226.1, C227.2, C229.2, C230.2, C232.2, C236.2, C237.2, C238.2, C239.1, C240.2, C241.2, C242.2, C243.2, C244.1, C245.2, C246.2, C247.2, C248.2, C249.2, C250.2, C301.1, C302.1, C303.2, C304.2, C305.2, C306.2, C307.2, C308.2, C309.2, C310.2, C311.1, C312.2, C319.2, C321.2, C322.2, C325.1, C326.1, C327.2, C329.2, C330.2, C332.2, C336.2, C337.2, C338.2, C339.1, C340.2, C341.2, C342.2, C343.2, C344.1, C345.2, C346.2, C347.2, C348.2, C349.2, C350.2, C401.1, C402.1, C403.2, C404.2, C405.2, C406.2, C407.2, C408.2, C409.2, C410.2, C411.1, C412.2, C419.2, C421.2, C422.2, C425.1, C426.1, C427.2, C429.2, C430.2, C432.2, C436.2, C437.2, C438.2, C439.1, C440.2, C441.2, C442.2, C443.2, C444.1, C445.2, C446.2, C447.2, C448.2, C449.2, C450.2, C501.1, C502.1, C503.2, C504.2, C505.2, C506.2, C507.2, C508.2, C509.2, C510.2, C511.1, C512.2, C519.2, C521.2, C522.2, C525.1, C526.1, C527.2, C529.2, C530.2, C532.2, C536.2, C537.2, C538.2, C539.1, C540.2, C541.2, C542.2, C543.2, C544.1, C545.2, C546.2, C547.2, C548.2, C549.2, C550.2, J1.5, J201.2, J301.2, J401.2, J501.2, R207.1, R208.1, R214.1, R215.1, R216.1, R217.2, R221.1, R222.1, R226.1, R227.1, R228.1, R232.1, R233.1, R235.1, R237.1, R242.1, R307.1, R308.1, R314.1, R315.1, R316.1, R317.2, R321.1, R322.1, R326.1, R327.1, R328.1, R332.1, R333.1, R335.1, R337.1, R342.1, R407.1, R408.1, R414.1, R415.1, R416.1, R417.2, R421.1, R422.1, R426.1, R427.1, R428.1, R432.1, R433.1, R435.1, R437.1, R442.1, R507.1, R508.1, R514.1, R515.1, R516.1, R517.2, R521.1, R522.1, R526.1, R527.1, R528.1, R532.1, R533.1, R535.1, R537.1, R542.1, SW1.2, U1.1, U2.4, U3.4, U3.7, U3.13, U3.17, U3.19, U3.21, U3.33, U3.35, U3.48, U5.2, U5.3, U5.4, U5.7, U6.2, U201.2, U201.4, U201.5, U202.41, U203.A3, U203.B3, U204.2, U205.4, U206.A3, U206.B3, U207.2, U301.2, U301.4, U301.5, U302.41, U303.A3, U303.B3, U304.2, U305.4, U306.A3, U306.B3, U307.2, U401.2, U401.4, U401.5, U402.41, U403.A3, U403.B3, U404.2, U405.4, U406.A3, U406.B3, U407.2, U501.2, U501.4, U501.5, U502.41, U503.A3, U503.B3, U504.2, U505.4, U506.A3, U506.B3, U507.2, X1.2, X2.2
unnamed: C4.1, L2.1, U1.3, U6.1
unnamed: C16.2, U3.12
unnamed: C18.1, R6.2, SW1.1, U3.49
unnamed: C21.1, L1.1, L2.2
unnamed: C213.1, C216.1, U201.6
unnamed: C213.2, C216.2, C218.2, J201.1
unnamed: C214.1, C217.1, R205.2
unnamed: C214.2, C217.2, U201.3
unnamed: C215.1, U202.3
unnamed: C215.2, R204.1
unnamed: C218.1, L201.1
unnamed: C219.1, U202.4
unnamed: C220.1, U202.6
unnamed: C220.2, R213.1
unnamed: C221.1, U202.7
unnamed: C222.1, U202.9
unnamed: C223.1, U202.10
unnamed: C223.2, R220.1
unnamed: C228.1, U202.24
unnamed: C228.2, R225.1
unnamed: C229.1, U202.25
unnamed: C230.1, U202.37
unnamed: C231.1, U202.38
unnamed: C232.1, U202.39
unnamed: C233.1, U202.40
unnamed: C233.2, R231.1
unnamed: C234.1, U202.20
unnamed: C235.1, C236.1, R234.1, U202.27
unnamed: C235.2, R235.2, U202.26
unnamed: C237.1, R234.2, U202.28
unnamed: C313.1, C316.1, U301.6
unnamed: C313.2, C316.2, C318.2, J301.1
unnamed: C314.1, C317.1, R305.2
unnamed: C314.2, C317.2, U301.3
unnamed: C315.1, U302.3
unnamed: C315.2, R304.1
unnamed: C318.1, L301.1
unnamed: C319.1, U302.4
unnamed: C320.1, U302.6
unnamed: C320.2, R313.1
unnamed: C321.1, U302.7
unnamed: C322.1, U302.9
unnamed: C323.1, U302.10
unnamed: C323.2, R320.1
unnamed: C328.1, U302.24
unnamed: C328.2, R325.1
unnamed: C329.1, U302.25
unnamed: C330.1, U302.37
unnamed: C331.1, U302.38
unnamed: C332.1, U302.39
unnamed: C333.1, U302.40
unnamed: C333.2, R331.1
unnamed: C334.1, U302.20
unnamed: C335.1, C336.1, R334.1, U302.27
unnamed: C335.2, R335.2, U302.26
unnamed: C337.1, R334.2, U302.28
unnamed: C413.1, C416.1, U401.6
unnamed: C413.2, C416.2, C418.2, J401.1
unnamed: C414.1, C417.1, R405.2
unnamed: C414.2, C417.2, U401.3
unnamed: C415.1, U402.3
unnamed: C415.2, R404.1
unnamed: C418.1, L401.1
unnamed: C419.1, U402.4
unnamed: C420.1, U402.6
unnamed: C420.2, R413.1
unnamed: C421.1, U402.7
unnamed: C422.1, U402.9
unnamed: C423.1, U402.10
unnamed: C423.2, R420.1
unnamed: C428.1, U402.24
unnamed: C428.2, R425.1
unnamed: C429.1, U402.25
unnamed: C430.1, U402.37
unnamed: C431.1, U402.38
unnamed: C432.1, U402.39
unnamed: C433.1, U402.40
unnamed: C433.2, R431.1
unnamed: C434.1, U402.20
unnamed: C435.1, C436.1, R434.1, U402.27
unnamed: C435.2, R435.2, U402.26
unnamed: C437.1, R434.2, U402.28
unnamed: C513.1, C516.1, U501.6
unnamed: C513.2, C516.2, C518.2, J501.1
unnamed: C514.1, C517.1, R505.2
unnamed: C514.2, C517.2, U501.3
unnamed: C515.1, U502.3
unnamed: C515.2, R504.1
unnamed: C518.1, L501.1
unnamed: C519.1, U502.4
unnamed: C520.1, U502.6
unnamed: C520.2, R513.1
unnamed: C521.1, U502.7
unnamed: C522.1, U502.9
unnamed: C523.1, U502.10
unnamed: C523.2, R520.1
unnamed: C528.1, U502.24
unnamed: C528.2, R525.1
unnamed: C529.1, U502.25
unnamed: C530.1, U502.37
unnamed: C531.1, U502.38
unnamed: C532.1, U502.39
unnamed: C533.1, U502.40
unnamed: C533.2, R531.1
unnamed: C534.1, U502.20
unnamed: C535.1, C536.1, R534.1, U502.27
unnamed: C535.2, R535.2, U502.26
unnamed: C537.1, R534.2, U502.28
unnamed: D1.1, U3.40
unnamed: D1.2, R8.2
unnamed: D2.1, U3.41
unnamed: D2.2, R7.2
unnamed: L3.2, L4.1
unnamed: L201.2, L202.1
unnamed: L202.2, R217.1, R246.2
unnamed: L301.2, L302.1
unnamed: L302.2, R317.1, R346.2
unnamed: L401.2, L402.1
unnamed: L402.2, R417.1, R446.2
unnamed: L501.2, L502.1
unnamed: L502.2, R517.1, R546.2
unnamed: R1.1, U2.7
unnamed: R2.1, U2.6
unnamed: R3.2, U2.2
unnamed: R4.2, U2.3
unnamed: R5.2, U2.5, X1.3
unnamed: R9.2, U3.23, U5.5
unnamed: R10.2, U3.22, U5.6
unnamed: R201.2, R205.1, R206.2, R209.2
unnamed: R202.1, R203.2, R207.2
unnamed: R203.1, R204.2, R208.2
unnamed: R210.1, R211.2, R214.2
unnamed: R211.1, R212.2, R215.2
unnamed: R212.1, R213.2, R216.2
unnamed: R218.1, R219.2, R221.2
unnamed: R219.1, R220.2, R222.2
unnamed: R223.1, R224.2, R227.2
unnamed: R224.1, R225.2, R228.2
unnamed: R229.1, R230.2, R232.2
unnamed: R230.1, R231.2, R233.2
unnamed: R236.1, R237.2, U205.3
unnamed: R238.2, R240.1, U205.1
unnamed: R239.1, R240.2, U205.2
unnamed: R241.1, R242.2, U205.7
unnamed: R243.2, R245.1, U205.9
unnamed: R244.1, R245.2, U205.8
unnamed: R301.2, R305.1, R306.2, R309.2
unnamed: R302.1, R303.2, R307.2
unnamed: R303.1, R304.2, R308.2
unnamed: R310.1, R311.2, R314.2
unnamed: R311.1, R312.2, R315.2
unnamed: R312.1, R313.2, R316.2
unnamed: R318.1, R319.2, R321.2
unnamed: R319.1, R320.2, R322.2
unnamed: R323.1, R324.2, R327.2
unnamed: R324.1, R325.2, R328.2
unnamed: R329.1, R330.2, R332.2
unnamed: R330.1, R331.2, R333.2
unnamed: R336.1, R337.2, U305.3
unnamed: R338.2, R340.1, U305.1
unnamed: R339.1, R340.2, U305.2
unnamed: R341.1, R342.2, U305.7
unnamed: R343.2, R345.1, U305.9
unnamed: R344.1, R345.2, U305.8
unnamed: R401.2, R405.1, R406.2, R409.2
unnamed: R402.1, R403.2, R407.2
unnamed: R403.1, R404.2, R408.2
unnamed: R410.1, R411.2, R414.2
unnamed: R411.1, R412.2, R415.2
unnamed: R412.1, R413.2, R416.2
unnamed: R418.1, R419.2, R421.2
unnamed: R419.1, R420.2, R422.2
unnamed: R423.1, R424.2, R427.2
unnamed: R424.1, R425.2, R428.2
unnamed: R429.1, R430.2, R432.2
unnamed: R430.1, R431.2, R433.2
unnamed: R436.1, R437.2, U405.3
unnamed: R438.2, R440.1, U405.1
unnamed: R439.1, R440.2, U405.2
unnamed: R441.1, R442.2, U405.7
unnamed: R443.2, R445.1, U405.9
unnamed: R444.1, R445.2, U405.8
unnamed: R501.2, R505.1, R506.2, R509.2
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

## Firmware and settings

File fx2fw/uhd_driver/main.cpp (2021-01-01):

/**
 * Copyright (C) 2009 Ubixum, Inc. 
 * Copyright (C) 2020 William Woods
 *
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
 * You should have received a copy of the GNU Lesser General Public
 * License along with this library; if not, write to the Free Software
 * Foundation, Inc., 51 Franklin Street, Fifth Floor, Boston, MA  02110-1301  USA
 **/

#include <stdio.h>
#include <string.h>
#include <assert.h>
#include <semaphore.h>
#include <pthread.h>
#include <libusb-1.0/libusb.h>

#include "tuner_msi001.h"
#include "mirisdr_reg.h"
#include "transpose.h"

const uint16_t VID = 0x04b4;
const uint16_t PID = 0x8613;

const unsigned char EP2_IN_ADDR = LIBUSB_ENDPOINT_IN | 0x02;

// for asynchronous bulk transfers
#define N_CONCURRENT 10 
sem_t transfer_slots;
sem_t rbuff_slots;
sem_t fwrite_mutex;
bool write_raw_transposed = true;
// this handles each incoming usb packet when using the asynchronous libusb functions
void async_recv_cb(struct libusb_transfer* transfer) {
  sem_post(&transfer_slots);
  sem_wait(&fwrite_mutex);

  if (write_raw_transposed && transfer->actual_length == 507) {
    // TODO: alignment here maybe? might want to figure out where the data is being lost first though
    for (int i = 0; i < transfer->actual_length/13; i++) {
      uint16_t channels[8];
      transpose_ADC_reading(transfer->buffer + i*13 + 1, channels, false);

      float CH1[2];
      CH1[0] = (((float) channels[6]) - 2048.f) / 4096.f;
      CH1[1] = (((float) channels[7]) - 2048.f) / 4096.f;
      fwrite(CH1, sizeof(float), 2, stdout); // just write channel 1 (hacky)

      //fwrite(channels, 1, 16, stdout);
    }
  } else {
    fwrite(transfer->buffer, 1, transfer->actual_length, stdout);
  }

  sem_post(&fwrite_mutex);
  sem_post(&rbuff_slots);

  libusb_free_transfer(transfer);
}
bool libusb_event_thread_run = false;
void* libusb_event_thread_fn(void* ctx) {
  while (libusb_event_thread_run) {
    libusb_handle_events((libusb_context*) ctx);
  }
  printf("exiting libusb event thread!\n");
  return NULL;
}

// for sending data to the MSi001 chips, via a vendor command to the FX2LP
bool send_over_spi_bridge(libusb_device_handle* hndl, uint8_t channel_sel, uint8_t* data, uint8_t len) {
  // host to device | vendor command | recipient is an endpoint
  uint8_t bmRequestType = (0 << 7) | (2 << 5) | (2 << 0); 
  uint8_t bRequest = 0xB0; // the FX2LP FW recognises this as a command to send the data out over SPI
  uint16_t wValue = (uint16_t) channel_sel;

  int rv = libusb_control_transfer(
    hndl,
    bmRequestType,
    bRequest,
    wValue,
    0x0000,
    data,
    len,
    100
  );

  if (rv != len) {
    printf("Couldn't send over spi bridge. Libusb: %s\n", libusb_error_name(rv));
    return false;
  }

  return true;
}
// tuner_msi001.c makes calls to this fn to write to the MSi001 tuners
int mirisdr_reg_write_fn(void *dev, uint8_t reg, uint32_t val) {
  // FX2LP will send out each byte MSB first
  // However, we need to swap byte order so MSByte goes first 
  uint8_t data[3];
  data[0] = (val >> 16) & 0xFF;
  data[1] = (val >>  8) & 0xFF;
  data[2] = (val >>  0) & 0xFF;
  send_over_spi_bridge((libusb_device_handle*) dev, 0x0F, data, 3);
}

// testing out this msi001 tuner library
void do_msi001_lib_test(libusb_device_handle* hndl) {
  void* dev = (void*) hndl;
  uint32_t freq = 100000000;
  msi001_init(dev, freq);
}

int main(int argc, char* argv[]) {

  int rv;

  libusb_context* ctx;
  libusb_init(&ctx);
  
  // TODO: this is a "convenience function" not intended for final use
  // because if multiple devices share PID/VID then it only opens the first.
  //
  // Should be using lib_usb_get_device_list at some point before, and opening
  // that way.
  libusb_device_handle* hndl = libusb_open_device_with_vid_pid(ctx, VID, PID);
  if (hndl == NULL) {
    printf("Could not find device %4x:%4x\n", VID, PID);
    return -1;
  }

  rv = libusb_set_auto_detach_kernel_driver(hndl, 1);
  if (rv != 0) {
    printf("Found device, but could not auto-detach kernel driver! Continuing anway...\n");
  }

  // "instruct the underlying operating system that your application wishes to take ownership of the interface."
  rv = libusb_claim_interface(hndl, 0);
  if (rv != 0) {
    printf("Found device, but could not claim interface!\n");
    return -1;
  }

  rv = libusb_set_interface_alt_setting(hndl, 0, 0);
  if (rv != 0) {
    printf("Found device and claimed interface but could not set alt interface!\n");
    return -1;
  }

  // send control transfer if we have been called with them as args
  if (argc == 4) {
    // host to device | vendor command | recipient is an endpoint
    uint8_t bmRequestType = (0 << 7) | (2 << 5) | (2 << 0); 
    uint16_t wValue;
    uint8_t bRequest;

    unsigned int tmp;
    sscanf(argv[1], "0x%02x", &tmp);
    bRequest = tmp & (0xFF);

    sscanf(argv[2], "0x%04x", &tmp);
    wValue = tmp & (0xFFFF);

    uint8_t data[64];
    int i = 0;
    int chars_read = 0;
    for (;i < strlen(argv[3]); i += 2) {
      int n;
      sscanf(&(argv[3][i]), "%2hhx%n", data + i/2, &n);
      chars_read += n;
    }
    if (chars_read % 2) {
      printf("Expected even number of hex chars for data. Zero pad if necessary!\n");
      return -1;
    }
    uint8_t data_len = chars_read / 2; // in bytes
    printf("Sending bRequest 0x%02x with wValue: 0x%04x, Data is %d bytes long\n%s\n", bRequest, wValue, data_len, (char*) data);

    rv = libusb_control_transfer(
      hndl,
      bmRequestType,
      bRequest,
      wValue,
      0x0000,
      data,
      data_len,
      1000
    );

    if (rv != data_len) {
      printf("Couldn't send. Libusb: %s\n", libusb_error_name(rv));
      return -1;
    }
    return 0;

  } else {
/*
    uint8_t bmRequestType = (0 << 7) | (2 << 5) | (2 << 0); 
    uint8_t data[6] = "hello";
    rv = libusb_control_transfer(
      hndl,
      bmRequestType,
      0xB0,
      0x000F,
      0x0000,
      data,
      4,
      100
    );
    if (rv != 0) {
      printf("Couldn't send over spi bridge. Libusb: %s\n", libusb_error_name(rv));
      return false;
    }
*/
    do_msi001_lib_test(hndl);
  }

  if (argc == 2) {
    // stream to stdout (can pipe this into a file for later analysis, for example)

    if (strcmp(argv[1], "-t") == 0)
      write_raw_transposed = true;
    else
      write_raw_transposed = false;
    
    const int RBUFF_LEN = 2 * N_CONCURRENT;
    struct libusb_transfer* transfers_rbuff[RBUFF_LEN];
    unsigned char data_rbuff[RBUFF_LEN][507];
    int rbuff_head = 0;

    sem_init(&transfer_slots, 0, N_CONCURRENT);
    sem_init(&rbuff_slots, 0, RBUFF_LEN);
    sem_init(&fwrite_mutex, 0, 1);

    pthread_t event_thread;
    libusb_event_thread_run = true;
    pthread_create(&event_thread, NULL, libusb_event_thread_fn, ctx);

    while (1) {
      sem_wait(&rbuff_slots);
      sem_wait(&transfer_slots);
      
      // assume these transfers we launch come back in the same order
      transfers_rbuff[rbuff_head] = libusb_alloc_transfer(0);
      struct libusb_transfer* transfer = transfers_rbuff[rbuff_head];
      if (transfer == NULL) {
        printf("Couldn't allocate transfer.");
        sem_post(&transfer_slots);
        sem_post(&rbuff_slots);
        continue;
      }
      libusb_fill_bulk_transfer(transfer, hndl, EP2_IN_ADDR, data_rbuff[rbuff_head], 507,
                                async_recv_cb, NULL, 100);
      rv = libusb_submit_transfer(transfer);
      if (rv != 0) {
        printf("Couldn't submit transfer: %s\n", libusb_error_name(rv));
        libusb_free_transfer(transfer);
        sem_post(&transfer_slots);
        sem_post(&rbuff_slots);
        continue;
      }

      rbuff_head = (rbuff_head + 1) % RBUFF_LEN;
    }

    // TODO: proper termination of the event_thread
    //libusb_event_thread_run = false;
    //pthread_join(event_thread, NULL);
    
  } else if (argc == 1) {
    // print some lines of user-readable data

    unsigned char buf2[6*507];
    int nTransferred = 0;

    for (int i = 0; i < sizeof(buf2) / 507; i++) {
      // TODO: this is blocking; need to look into the async version
      rv = libusb_bulk_transfer(hndl, EP2_IN_ADDR, buf2 + i*507, 507, &nTransferred, 500);
      if (rv) {
        printf ( "IN Transfer failed: %d, transferred: %d\n", rv, nTransferred );
        return rv;
      }
    }

    // See what we read in
    printf("Read in %d bytes\n", nTransferred);
  /*
    // the raw hex we got
    for (int i=0;i<nTransferred;++i) {
      if (i % 13 == 0) printf("\n");
      printf ( "%02x ", buf2[i] );
    }
  */
    printf("\n");
    // transposed so we can see what each channel saw
    printf("n\tCH0\tCH1\tCH2\tCH3\tCH4\tCH5\tCH6\tCH7\n");
    for (int i = 0; i < sizeof(buf2)/13; i++) {
      uint16_t channels[8];
      transpose_ADC_reading(buf2 + i*13, channels, false);
      printf("%d:\t", i);
      for (int j = 0; j < 8; j++)
        printf("%03x\t", channels[j]);
      printf("\n");
    }
  } else {
    printf("Expected ./main [<bRequest> <wValue> <data>] or -[s|t]");
  }

  return 0;
}

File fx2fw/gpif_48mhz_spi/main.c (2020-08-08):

/*
 * This file is part of the sigrok-firmware-fx2lafw project.
 *
 * Copyright (C) 2011-2012 Uwe Hermann <uwe@hermann-uwe.de>
 *
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
 * You should have received a copy of the GNU General Public License
 * along with this program; if not, see <http://www.gnu.org/licenses/>.
 */

/*
 * fx2lafw is an open-source firmware for Cypress FX2 based logic analyzers.
 *
 * It is written in C, using fx2lib as helper library, and sdcc as compiler.
 * The code is licensed under the terms of the GNU GPL, version 2 or later.
 *
 * Technical notes:
 *
 *  - We use the FX2 in GPIF mode to sample the data (asynchronously).
 *  - We use the internal 48MHz clock for GPIF.
 *  - The 8 channels/pins we sample (the GPIF data bus) are PB0-PB7,
 *    or PB0-PB7 + PD0-PD7 for 16-channel sampling. 
 *  - Endpoint 2 (quad-buffered) is used for data transfers from FX2 to host.
 *
 * Documentation:
 *
 *  - See http://sigrok.org/wiki/Fx2lafw
 */

#include <fx2regs.h>
#include <fx2macros.h>
#include <fx2ints.h>
#include <delay.h>
#include <setupdat.h>
#include <eputils.h>
#include <gpif.h>
#include <command.h>
#include <fx2lafw.h>
#include <gpif-acquisition.h>

// used by RESETFIFO macro
//#define SYNCDELAY SYNCDELAY4

/* ... */
volatile __bit got_sud;
BYTE vendor_command;

volatile WORD ledcounter = 0;

static void setup_endpoints(void)
{
	/* Setup EP2 (IN). */
	EP2CFG = (1u << 7) |		  /* EP is valid/activated */
		 (1u << 6) |		  /* EP direction: IN */
		 (1u << 5) | (0u << 4) |  /* EP Type: bulk */
		 (1u << 3) |		  /* EP buffer size: 1024 */
		 (0u << 2) |		  /* Reserved. */
		 (0u << 1) | (0u << 0);	  /* EP buffering: quad buffering */
	SYNCDELAY;

	/* Disable all other EPs (EP1, EP4, EP6, and EP8). */
	EP1INCFG &= ~bmVALID;
	SYNCDELAY;
	EP1OUTCFG &= ~bmVALID;
	SYNCDELAY;
	EP4CFG &= ~bmVALID;
	SYNCDELAY;
	EP6CFG &= ~bmVALID;
	SYNCDELAY;
	EP8CFG &= ~bmVALID;
	SYNCDELAY;

	/* EP2: Reset the FIFOs. */
	/* Note: RESETFIFO() gets the EP number WITHOUT bit 7 set/cleared. */
	RESETFIFO(0x02);

	/* EP2: Enable AUTOIN mode. Set FIFO width to 8bits. */
	EP2FIFOCFG = bmAUTOIN;
	SYNCDELAY;

	/* EP2: Auto-commit 512 (0x200) byte packets (due to AUTOIN = 1). */
	EP2AUTOINLENH = 0x02;
	SYNCDELAY;
	EP2AUTOINLENL = 0x00;
	SYNCDELAY;

	/* EP2: Set the GPIF flag to 'full'. */
	EP2GPIFFLGSEL = (1 << 1) | (0 << 1);
	SYNCDELAY;
}

static void send_fw_version(void)
{
	/* Populate the buffer. */
	struct version_info *const vi = (struct version_info *)EP0BUF;
	vi->major = FX2LAFW_VERSION_MAJOR;
	vi->minor = FX2LAFW_VERSION_MINOR;

	/* Send the message. */
	EP0BCH = 0;
	SYNCDELAY;
	EP0BCL = sizeof(struct version_info);
	SYNCDELAY;
}

static void send_revid_version(void)
{
	uint8_t *p;

	/* Populate the buffer. */
	p = (uint8_t *)EP0BUF;
	*p = REVID;

	/* Send the message. */
	EP0BCH = 0;
	SYNCDELAY;
	EP0BCL = 1;
	SYNCDELAY;
}

BOOL handle_vendorcommand(BYTE cmd)
{
	/* Protocol implementation */
	switch (cmd) {
	case CMD_START:
		/* Tell hardware we are ready to receive data. */
		vendor_command = cmd;
		EP0BCL = 0;
		SYNCDELAY;
		return TRUE;
	case CMD_GET_FW_VERSION:
		send_fw_version();
		return TRUE;
	case CMD_GET_REVID_VERSION:
		send_revid_version();
		return TRUE;
	}

	return FALSE;
}

BOOL handle_get_interface(BYTE ifc, BYTE *alt_ifc)
{
	/* We only support interface 0, alternate interface 0. */
	if (ifc != 0)
		return FALSE;

	*alt_ifc = 0;
	return TRUE;
}

BOOL handle_set_interface(BYTE ifc, BYTE alt_ifc)
{
	/* We only support interface 0, alternate interface 0. */
	if (ifc != 0 || alt_ifc != 0)
		return FALSE;

	/* Perform procedure from TRM, section 2.3.7: */

	/* (1) TODO. */

	/* (2) Reset data toggles of the EPs in the interface. */
	/* Note: RESETTOGGLE() gets the EP number WITH bit 7 set/cleared. */
	RESETTOGGLE(0x82);

	/* (3) Restore EPs to their default conditions. */
	/* Note: RESETFIFO() gets the EP number WITHOUT bit 7 set/cleared. */
	RESETFIFO(0x02);
	/* TODO */

	/* (4) Clear the HSNAK bit. Not needed, fx2lib does this. */

	return TRUE;
}

BYTE handle_get_configuration(void)
{
	/* We only support configuration 1. */
	return 1;
}

BOOL handle_set_configuration(BYTE cfg)
{
	/* We only support configuration 1. */
	return (cfg == 1) ? TRUE : FALSE;
}

void sudav_isr(void) __interrupt SUDAV_ISR
{
	got_sud = TRUE;
	CLEAR_SUDAV();
}

/* IN BULK NAK - the host started requesting data. */
void ibn_isr(void) __interrupt IBN_ISR
{
	/*
	 * If the IBN interrupt is not disabled, clearing
	 * does not work. See AN78446, 6.2.
	 */
	BYTE ibnsave = IBNIE;
	IBNIE = 0;
	CLEAR_USBINT();

	/*
	 * If the host sent the START command, start the GPIF
	 * engine. The host will repeat the BULK IN in the next
	 * microframe.
	 */
	if ((IBNIRQ & bmEP2IBN) && (gpif_acquiring == PREPARED)) {
		ledcounter = 1;
		LED_OFF();
		gpif_acquisition_start();
	}

	/* Clear IBN flags for all EPs. */
	IBNIRQ = 0xff;

	NAKIRQ = bmIBN;
	SYNCDELAY;

	IBNIE = ibnsave;
	SYNCDELAY;
}

void usbreset_isr(void) __interrupt USBRESET_ISR
{
	handle_hispeed(FALSE);
	CLEAR_USBRESET();
}

void hispeed_isr(void) __interrupt HISPEED_ISR
{
	handle_hispeed(TRUE);
	CLEAR_HISPEED();
}

void timer2_isr(void) __interrupt TF2_ISR
{
	/* Blink LED during acquisition, keep it on otherwise. */
	if (gpif_acquiring == RUNNING) {
		if (--ledcounter == 0) {
			LED_TOGGLE();
			ledcounter = 1000;
		}
	} else if (gpif_acquiring == STOPPED) {
		LED_ON();
	}
	TF2 = 0;
}

void fx2lafw_init(void)
{
	/* Set DYN_OUT and ENH_PKT bits, as recommended by the TRM. */
	REVCTL = bmNOAUTOARM | bmSKIPCOMMIT;

	got_sud = FALSE;
	vendor_command = 0;

	/* Renumerate. */
	RENUMERATE_UNCOND();

	SETCPUFREQ(CLK_48M);

	USE_USB_INTS();

	/* TODO: Does the order of the following lines matter? */
	ENABLE_SUDAV();
	ENABLE_EP2IBN();
	ENABLE_HISPEED();
	ENABLE_USBRESET();

	LED_INIT();
	LED_ON();

	/* Init timer2. */
	RCAP2L = -500 & 0xff;
	RCAP2H = (-500 & 0xff00) >> 8;
	T2CON = 0;
	ET2 = 1;
	TR2 = 1;

	/* Global (8051) interrupt enable. */
	EA = 1;

	/* Setup the endpoints. */
	setup_endpoints();

	/* Put the FX2 into GPIF master mode and setup the GPIF. */
	gpif_init_la();
}

void fx2lafw_poll(void)
{
	if (got_sud) {
		handle_setupdata();
		got_sud = FALSE;
	}

	if (vendor_command) {
		switch (vendor_command) {
		case CMD_START:
			if ((EP0CS & bmEPBUSY) != 0)
				break;

			if (EP0BCL == sizeof(struct cmd_start_acquisition)) {
				gpif_acquisition_prepare(
				 (const struct cmd_start_acquisition *)EP0BUF);
			}

			/* Acknowledge the vendor command. */
			vendor_command = 0;
			break;
		default:
			/* Unimplemented command. */
			vendor_command = 0;
			break;
		}
	}

	gpif_poll();
}

void main(void)
{
	fx2lafw_init();
	while (1)
		fx2lafw_poll();
}

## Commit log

2020-07-16 Added in all the files so far and updated README
    [SDR_board.kicad_pcb, SDR_board.sch]
2020-07-16 folder rename
    [SDR_board.kicad_pcb, SDR_board.sch]
2020-07-17 Drew circuit traces onto picture of existing msi001 implementation to assist with reverse engineering
2020-07-19 Started on an FPGA project which gets the FPGA to act like the ADC I plan to use (MAX11131), so data transfer back to the PC via the FX2LP can be developed
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2020-07-20 antenna_input_coupling.asc: drew in all the circuitry that has been reverse-engineered so far
2020-07-20 Changed over FPGA experiment to using the MAX19777 ADC, as this is what the project will be using now (8 of them)
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2020-07-20 Some screenshots and logic analyser capture results from the FPGA SPI ADC emulation
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2020-07-27 Bitrate calculation was wrong. Corrected this to take into account we have 8 ADCs (channels)
    [transpose_speed_test.c]
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2020-08-09 Fixed issue with reading device descriptor: this function needed to return something so the default would kick in
    [device.c]
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2020-08-09 on the trail of a bug; disabling this LED and timer stuff makes enumeration work again
    [device.c]
2020-08-10 Corrected LED polarity for my board. Switched to using PORTA0. Bug: soon as timer 2 starts, USB enumeration fails.
    [device.c]
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2020-08-10 Changed PID and VID to match the values before flashing (makes it easy to flash again when firmware is already loaded; don't have to reset)
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2020-08-20 Added FIFO reset on set_interface, not much effect. Changed auto-commit packet size to 1, for testing
    [device.c]
2020-08-21 Made gpif waveform infinitely execute. Also got its length correct so there's 16 cycles.
    [device.c]
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2020-08-23 Inverted clock output (so it appears as if we sample on the falling edge), gives more setup time. Trying it out.
    Also, the gpifwf ISR doesn't seem to trigger
    [device.c]
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2020-08-26 Added reset to FPGA_SPI_slave and changed pin assignments to use 'fast' input and outputs
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2020-08-28 Building out the schematics; added the MAX19777
    [channel.sch]
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2020-08-29 More work on the PCB schematic
    [SDR_board.sch, channel.sch]
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2020-09-04 Some stuff on modelling the LNA DC blocking caps and how that part is connected up
    [channel.sch]
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2020-09-06 Added charge pump circuit to PCB schematic
    [channel.sch]
2020-09-06 Reduced loop filter BW and avoided needing a new size of cap
    [channel.sch]
2020-09-06 Added decoupling to MSi001, also sorted out the proper lowpass filter and termination tap off the antenna to the high-Z input.
    [channel.sch]
2020-09-06 Split the inductors for the LP filter on input out into two smaller values, seems to correct for issues due to parasistic capacitance.
    [channel.sch]
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2020-09-06 Another, more hopeful attempt at a lazy resistive coupling between LNA and MSi001. This one has about 14dB of power loss to any given input. Pretty bad, but the LNA has 30dB gain.
    [antenna_input_coupling_resistive_2_loss_calcs.ods]
2020-09-06 DC blocking cap for LF part of antenna coupling. Don't think we want to let DC currents flow through us.
    [channel.sch]
2020-09-24 Distributing clock to devices
    [SDR_board.sch, channel.sch]
2020-09-25 Connected up the clock buffer
    [SDR_board.sch, channel.sch]
2020-09-25 Added in ADS7883 ADCs as the main ones
    [channel.sch]
2020-09-26 Some changes to decoupling
    [SDR_board.sch, channel.sch]
2020-09-27 more work on PCB
    [SDR_board.sch, channel.sch]
2020-09-27 Added second option for FX2LP clock source
    [SDR_board.sch]
2020-09-27 Duplicated the sheets for each channel.
    [SDR_board.sch, channel.sch]
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2020-09-28 Annotated schematic, changed some pin types on the ADCs as DRC was unhappy
    [SDR_board.sch, channel.sch]
2020-09-28 Finished footprint selection.
    [SDR_board.csv, SDR_board.sch, channel.sch]
2020-09-28 Changed power supply input filtering a bit
    [SDR_board.csv, SDR_board.sch, channel.sch]
2020-09-28 Put the oscillator and buffer onto the 'digital' supply rail, which should be fairly smooth. Concerned about the strong drivers on the buffer dirtying the analog supply rail.
    [SDR_board.sch]
2020-09-28 Changed schematic symbol used for the SMA connector
    [SDR_board.sch, channel.sch]
2020-09-28 Schematic sheet size change
    [SDR_board.sch, channel.sch]
2020-09-28 Replaced some of the 4.7uH inductors for 10uH power inductors
    [SDR_board.csv, SDR_board.sch, channel.sch]
2020-09-28 Removed some clutter
    [SDR_board.sch, channel.sch]
2020-09-28 layout is in progress, got one channel and the digital stuff approximately laid out.
    [SDR_board.kicad_pcb, SDR_board.sch, channel.sch]
2020-09-29 more component layout
    [SDR_board.kicad_pcb, channel.sch]
2020-09-29 Duplicated the layouts for the other channels successfully using an old version of MitjaNemec/Kicad_action_plugins
    [SDR_board.kicad_pcb]
2020-09-29 Got a channel fully laid out. Setup trace profiles
    [SDR_board.kicad_pcb, channel.sch]
2020-09-29 Tuner module mostly wired up, just gotta duplicate them and connect them together
    [SDR_board.kicad_pcb, channel.sch]
2020-09-29 Added e14 parts list
    [ShopCart.csv]
2020-09-29 few more routing changes
    [SDR_board.kicad_pcb]
2020-09-29 Stashing some possibly-breaking changes
    [SDR_board.kicad_pcb, SDR_board.sch, channel.sch]
2020-09-29 stashing some layout changes
    [SDR_board.kicad_pcb]
2020-09-29 Resized component labels on silkscreen
    [SDR_board.kicad_pcb]
2020-09-29 silkscreen looks good for channel 1; TODO: copy to other channels.
    [SDR_board.kicad_pcb]
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2020-09-29 Closed solder resist around the MSi001 packages
    [SDR_board.kicad_pcb]
2020-09-29 MSi001 was using rescued schematic symbol for some reason. Fixed this
    [SDR_board.sch, channel.sch]
2020-09-29 Duplicated all those changes to chanel 1 through to the other channels
    [SDR_board.kicad_pcb]
2020-09-29 Added two missing series termination resistors on the clock buffer
    [SDR_board.sch, channel.sch]
2020-09-29 simplified SPI clock source for the MSi001
    [SDR_board.kicad_pcb, channel.sch]
2020-09-29 Finished signal routing for ADCs at the tuner side
    [SDR_board.kicad_pcb]
2020-09-29 Think the channels are done this time, for real
    [SDR_board.kicad_pcb]
2020-09-30 Board layout complete
    [SDR_board.kicad_pcb]
2020-09-30 Silkscreening done
    [SDR_board.kicad_pcb]
2020-09-30 Final board design before sending it off to fab
    [SDR_board.csv, SDR_board.kicad_pcb, ShopCart.csv]
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2020-10-03 LED1_TOGGLE macro had a small but crucial error
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2020-10-04 Added the other modes to SPI, but the MSi001 datasheet indicates it uses mode 0, so won't bother testing the others too much
    [device.c, spi.c, spi.h]
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2020-10-21 Updated schematic to match some capacitors which were switched round in assembly
    [SDR_board.sch, channel.sch]
2020-10-21 Pulled the reserved pin of fx2lp to GND, per the fx2lp PCB dev guide
    [SDR_board.kicad_pcb, SDR_board.sch]
2020-10-23 Touched up a few things for producing diagrams for the final report
    [antenna_input_coupling_resistive_1.1_loss_calcs.ods]
2020-10-24 Basically a script to find and replace silkscreen text attributes in bulk
2020-10-24 Added generated gerbers for v0.1 into repo.
    [SDR_board-B.Mask.gbr, SDR_board-B.SilkS.gbr, SDR_board-Back_4.Cu.gbr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]
2020-10-25 Added channel order flipping to the transpose code, as HW channels are flipped
    [transpose_speed_test.c]
2020-10-25 Also added channel order flipping to the raw ADC data retrieval tool
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2020-10-27 Capturing on 16 clocks per ADC sample, was previously 13. (and a bunch of other changes to try and lazily avoid the need for packet alignment)
    This was intended to make all the alignments nice and so avoid needing to write code for aligning each packet. Has not worked, however. (are we losing data somewhere? How?)
    [device.c, main.cpp]
2020-10-27 Revert "Capturing on 16 clocks per ADC sample, was previously 13. (and a bunch of other changes to try and lazily avoid the need for packet alignment)"
    This reverts commit 4407046bb8bfd1232c1cb658693d012043e82c51.
    [device.c, main.cpp]
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2020-10-28 Put the transaction counter back up to being massive
    Thanks to pausing on the FIFO full flag, packets are coming through properly aligned--no more missing data.
    [device.c]
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2021-01-01 Added FW support for 1.875 Msps, with vendor commands 0xB1 and 0xB2 to select b/w 3M and 1.875M
    This helps avoid dropping samples on a busy USB hub
    [device.c, main.cpp]

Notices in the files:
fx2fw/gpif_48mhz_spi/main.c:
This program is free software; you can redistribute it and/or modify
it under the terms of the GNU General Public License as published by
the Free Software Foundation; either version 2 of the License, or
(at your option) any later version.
